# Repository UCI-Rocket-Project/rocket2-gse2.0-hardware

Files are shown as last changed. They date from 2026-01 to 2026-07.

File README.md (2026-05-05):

# rocket2 Ground Support Electronics (GSE) 
Current version: v2.1  
Documentation is rendered with MKDocs: [Click Here](https://uci-rocket-project.github.io/rocket2-gse2.0-hardware/)  

# CAD



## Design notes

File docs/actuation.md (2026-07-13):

# Overview
Last updated: 7/12/26

By: Robert Woo

The GSE supports 3 actuator types: Solenoid Valves, E-matches, and the Alarm.

The GSE includes:

- 12 Solenoid Valve output channel
- 2 E-match output channels
- 1 Alarm output channels

# Solenoid Valves

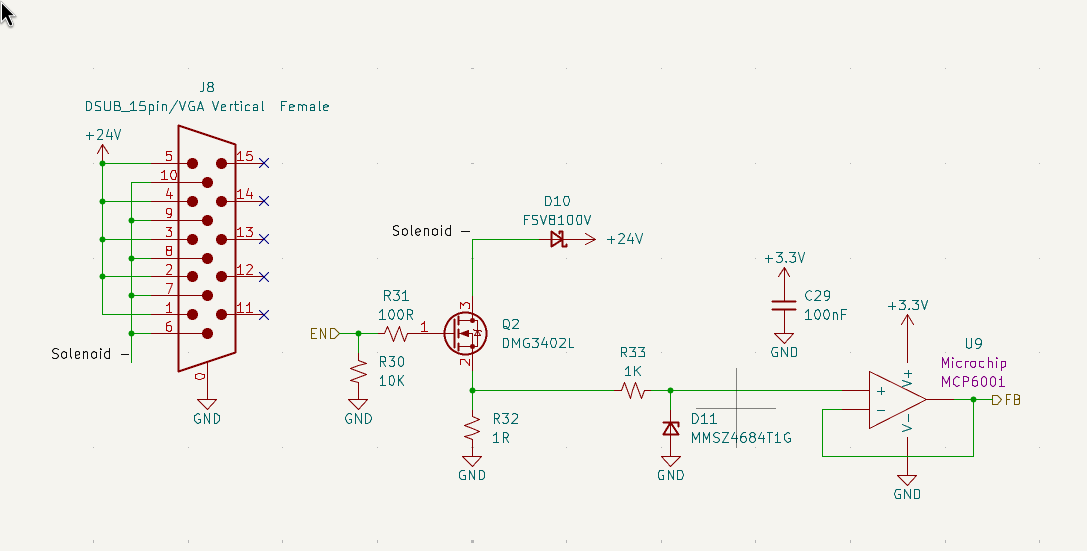
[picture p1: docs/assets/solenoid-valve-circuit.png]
Solenoid Valve Circuit


The GSE includes 12 solenoid valve out channels.

Solenoids are basically as inductors, which is why D10 is there. It's called a flyback diode, and its purpose is the allow the solenoids
to dissipate its stored magnetic field from an on-to-off state. D10's model has insanely high rating to deal with transients when current
on and off through an inductive element.

R31, R30, and Q2 are used to turn on and off the solenoid through the MCU's GPIO pin. R30 is for nominal off-state and R31 is to deal with overshoots in MOSFET gate voltages.

R32 should be a high wattage, 1 ohm resistor that is used primarily to read if there is current passing through the solenoid electrically.
Our solenoids draw about 500mA under 24V, so V=IR shows us that the voltage above R32 should be about 0.5V

The remaining components are double protection send this 0.5V back to an ADC pin on GSE's MCU. D11 is a zener diode which in combination 
with R33 will clamp unsafe voltage to the op-amp (U9) and pass thr current to ground. U9 just passed whatever voltage is at the + pin on 
op-amp, but acts as a buffer between the potential 24V that this circuit can see and potentially send to the MCU. You don't want to blow 
up the MCU by sending it 24V.

# E-matches

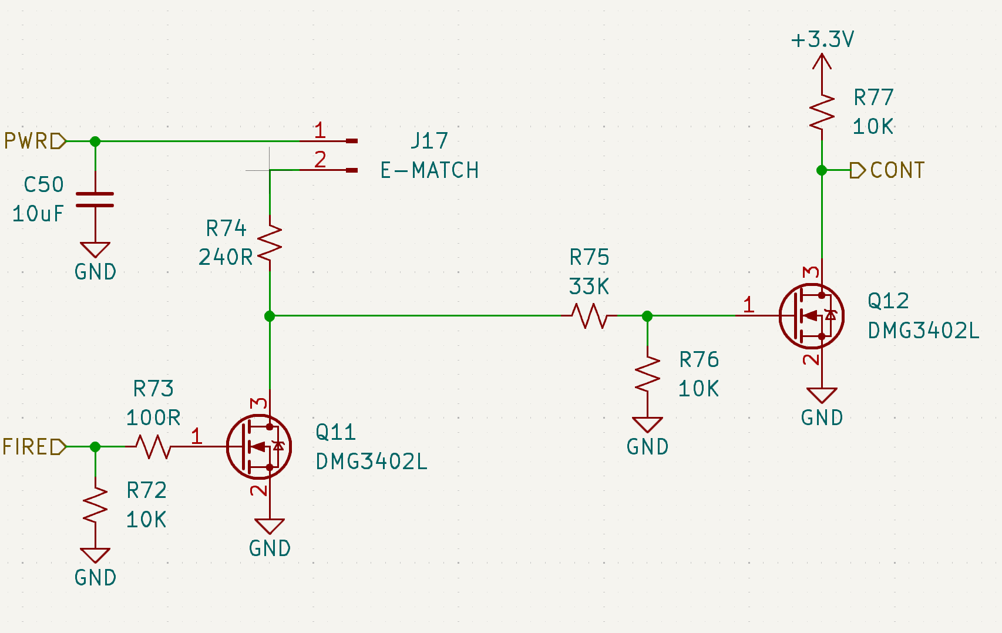
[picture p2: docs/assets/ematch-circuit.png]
E-match Circuit


The GSE includes 2 e-match output channels.

The e-match driver circuit uses a two-stage MOSFET switching configuration to safely control current delivery to the e-match load and read status of the circuit.

In the image, the node PWR will see either 0 or 24V depending on the if the arming is key is switched on or not to pass through the 
voltage

The CONT pin is a GPI that reads a logical high or low depending if there is voltage at the gate of the mosfet (Q12). If there is voltage
there, that means:

* the key is armed
* an ematch is connected between the screw terminals on GSE

R75 and R76 are used to step down the voltage to the gate of MOSFET to keep the voltages of the MOSFET in its operating range

R73, R72, and Q11 are used actually start an ematch. if FIRE goes to 3.3V from the MCU, the MOSFET will complete the circuit for the 
ematch to blow it.

**R74 is really important.** The MOSFET (DMG3402L) has a max current between drain and source (Id) of 4.0A. **R74 is there so that the MOSFET never fails from overcurrent. THe failure mode from overcurrent is the MOSFET always completing the circuit** 

# Alarm

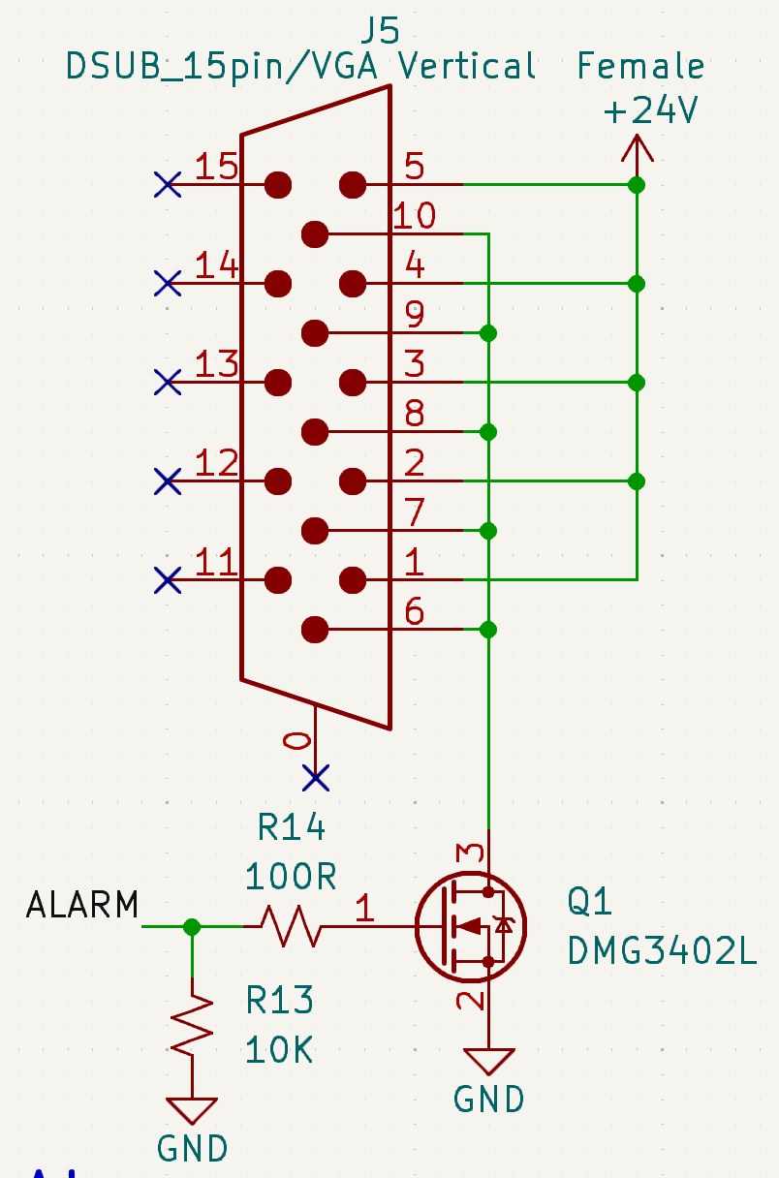
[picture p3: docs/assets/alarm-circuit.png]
Alarm Circuit


The GSE includes only 1 alarm output channel.

In the alarm driver circuit, a MCU GPIO control signal (ALARM) drives the gate of an N-channel MOSFET through a series resistor (R14). In parallel, a pull-down resistor (R13) tied to GND ensures a defined OFF state and prevents the build-up of residual charge.

Simple low-side mosfet switch

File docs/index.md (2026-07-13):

# GSE Docs
Last updated: 7/12/26

By: Robert Woo

## System Overview

For MOCH4, the GSE (Ground Support Electronics) is a 4-layer PCBA that controls the propulsion feedsystem on the ground. 

It is responsible for data collection from potentiometers, pressure transducers (PTs), and k-type thermocouplers (TC), and controls valve actuation through electric solenoids. 

Control is done entirely throught STM32F105RCT6 microntroller on the board and data collection collected either through the STM32 through the ethernet port on the back of the board or an NiDAQ (Currently a USB-6421) to collect this data from a PC.

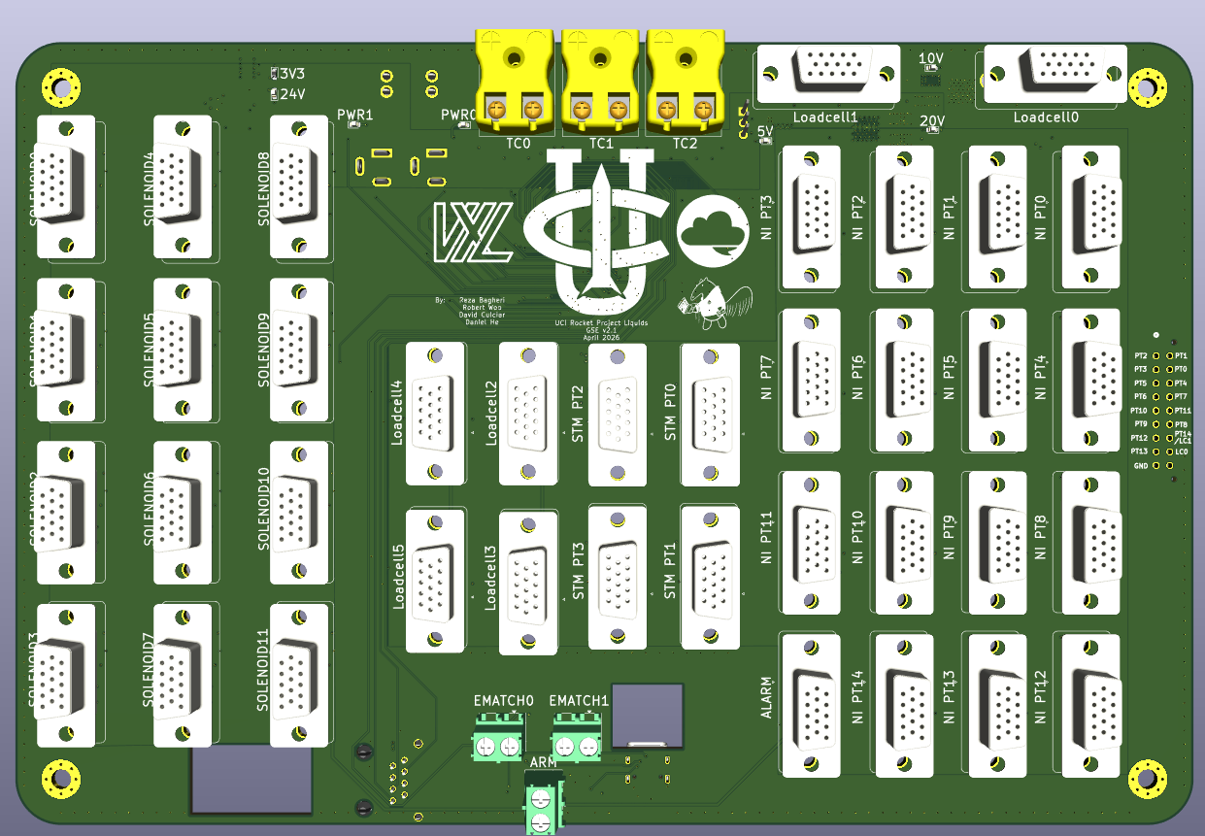
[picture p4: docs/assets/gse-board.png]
GSE PCB


## Inputs and Outputs
| Parameter | Value | Connector | Usage |
|---|---|---|---|
| Power ports | 24V DC, 2 redundant ports | 5.5mm barrel jack | Power board |
| Ethernet | 1 port | RJ45 uart-to-eth | Send/Recieve data 
| USB | 1 port | USB-C | Backup/debug data port, not in use|
| NiDAQ port | 1 port, 16 pins | 2x9 MOLEX | Output sensor voltages to NiDAQ |
| Solenoid ports | 24V 12 channels/ports | 15 pin, 3 row DSUB / VGA  | On/Off solenoid actuation |
| Ni PT ports | 20V 14/15 ports | 15 pin, 3 row DSUB / VGA  | Finds pressure readings to be read by the NIDAQ |
| STM32 PT ports | 20V 4 ports | 15 pin, 3 row DSUB / VGA  | Finds pressure readings to be read by an ADC, data transmitted over eth |
| Ni Loadcell ports | 10V 2 ports | 15 pin, 3 row DSUB / VGA  | Finds force readings from a 4 pin load to be read by the NiDAQ |
| STM32 Loadcell ports  | 10V 4 ports | 15 pin, 3 row DSUB / VGA  | Finds force readings from a 4 pin load cell to be read by an ADC data transmitted over eth |
| TC ports | 3 ports | 2 pin k-type TC plug | Reads temperature from a k-type TC, data sent over eth | 
| Ematch circuit | 2 ports, 1 arming port | Screw terminals | Sets off an e-match to start engine combustion |

## Circuits
- [Power](power.md)
- [Sensing](sensing.md) 
- [Compute](compute.md) TBD later
- [Communications](communications.md) TBD later
- [Actuation](actuation.md)

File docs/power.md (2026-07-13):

# Power
Last updated: 7/12/26

By: Robert Woo

The GSE takes in a 24V supply via 2 redundant, 5.5mm barrel jack connectors. Only 1 ports is needed to turn power the board. 1 buck regulator and 3 Linear Drop-outs 
(LDOs) are used to step down this input voltage to various voltages for sub-circuits on GSE v2.1

---

## Power Input

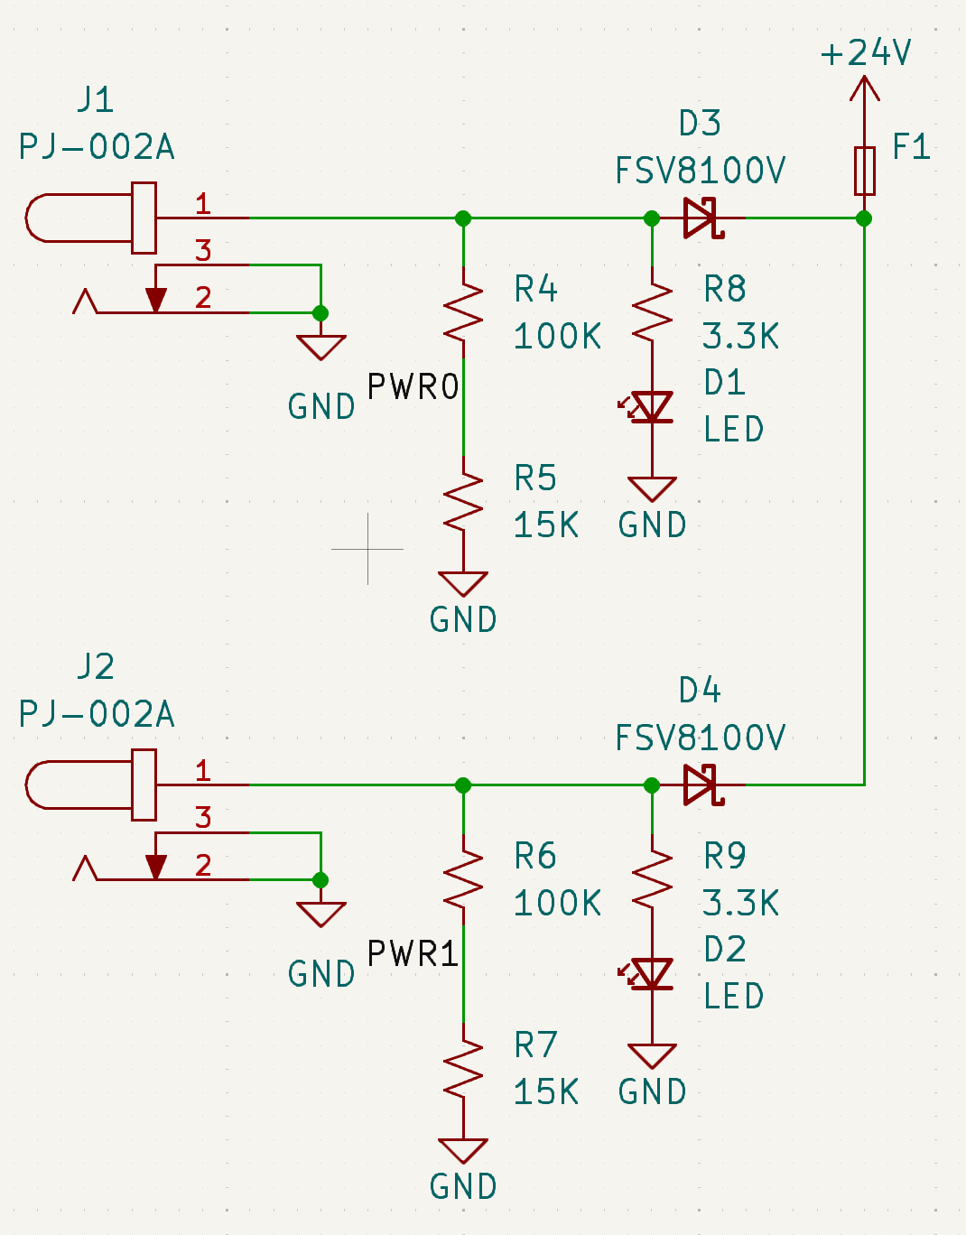
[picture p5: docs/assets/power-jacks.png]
Power Jacks


24V DC Power is accepted via two barrel jacks intended for redundant use, with only one input used at a time. Supplies the 24V power rail.

Each input is monitored by a voltage divider (R4 & R5, and R6 & R7), which feeds into the PWR0 and PWR1 GPIO pins for power detection and input voltage readings.

Schottky diodes (100V, 8A) are used to prevent current backflow between the 2, redundant, power supply inputs. 

LED indicators (D1 & D2) provide visual confirmation when input voltage is present at each jack.

Here's an example of what kind of power brick is used to power the board : 
[Power brick](https://www.amazon.com/dp/B0D5B33JCH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)

---

## Power regulators

GSE v2.1 currently has 3 LDOs and 1 buck regulator to power the following voltage rails:

| Component | Input Voltage | Output Voltage | Output Current |
|---|---|---|---|
| [Buck regulator (U5)](https://jlcpcb.com/partdetail/Monolithic_PowerSystems-MP2338GTLZ/C7210174) | 24V nominal | 3.3V | 3A |
| [LDO regulator (U2)](https://jlcpcb.com/partdetail/DiodesIncorporated-AS78L05RTRE1/C90471) | 24V nominal | 5V | 100 mA |
| [LDO regulator (U6)](https://jlcpcb.com/partdetail/TexasInstruments-UA78M10CKVURG3/C2868719) | 24V nominal | 10V | 500 mA |
| [LDO regulator (U7)](https://jlcpcb.com/partdetail/ROHMSemicon-BA78M20FPE2/C5336616s) | 24V nominal | 20V | 500 mA |

## Synchronous Buck Regulator: 3.3V Logic Level

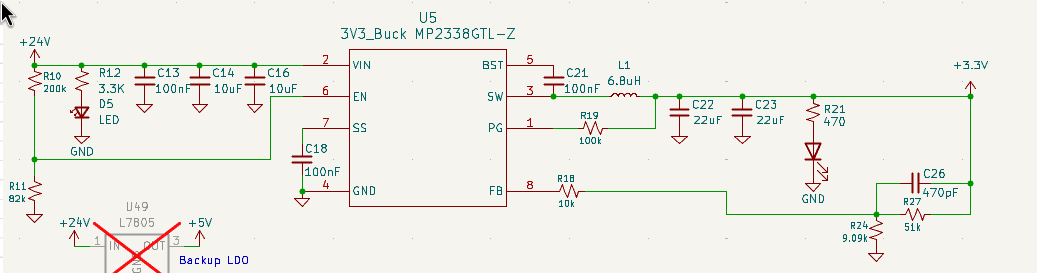
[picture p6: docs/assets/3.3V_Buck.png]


A synchronous buck regulator converts the 24V power rail into the 3.3V logic level supply rail. This circuit basically follows the datasheet exactly for a 3.3V 
output, and this buck converter was chosen mainly because it internally compensates the feedback loop. Aka, buck converters are hard and this synchronous buck 
converter, the higher efficency version, was easy AF in drop in.

---

### TROUBLESHOOTING / BUCK FAILURE

During usage of GSE v2.1 in Spring 2026, this buck converter failed/exploded after plugging in a 24V power supply into the barrel jacks of the board. This caused
everything on 3.3V bus to fry. DEAD AF BOARD

This was caused by inductive kick. Basically, wires has parasitive inductance in them. Inductors resists a change in current, and when you say, plug in a power
supply into a PCB, the inductance of the wires will causing an overshoot in voltage because current is basically infinite the moment charges start moving.

This was troubleshooted and found out mainly because GSE v2.1 was tested previously wiwth a DC power supply and shorter cables comparative to the 24 power brick
later used.

Inductive Kick
The picture above is just unplugging and replugging in the 24V power brick and reading the voltage that the buck converter would see with an oscilloscope with a single
shot trigger setting. As you can see, the buck converter sometime can see a max of 68V whenever you plug power in :0000000.

---

The solution: Put an electrolytic capacitor in parallel with Vin of the buck converter. Electrolytic capacitors generally have a high Equivalent Series Resistance (ESR)
can and was used on GSE v2.1 to slow down the infinite current that this buck converter would see.

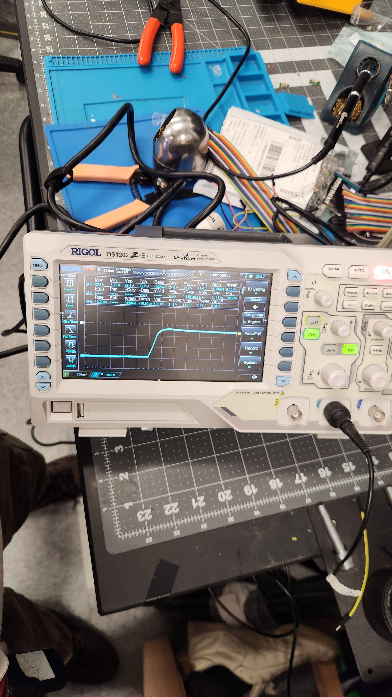
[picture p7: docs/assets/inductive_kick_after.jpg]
Inductive Kick

This was result with the oscilloscope probing the same point as before, but with an electrolytic capacitor in parallel with the other ceramic capacitors for the MP2338GTL-Z
Much better at dampening out the overshoot

---
#### Recommendation in the future:
&nbsp;

1. CHANGE THE BUCK CONVERTER IC

The MP2338GTL-Z has a highest input voltage rating 30V, which is low and why buck converter failed and killed everything from it downstream. NASA's derating guidelines say
to use components that can tolerate about 1.6 times the expected voltage range in normal operation. So get a buck converter that can take 38.4V or higher.

2. Still add the electrolytic capacitor in parallel with the next buck converter, just in case.

## Low Dropout (LDO) Regulators: 20V, 10V, 5V

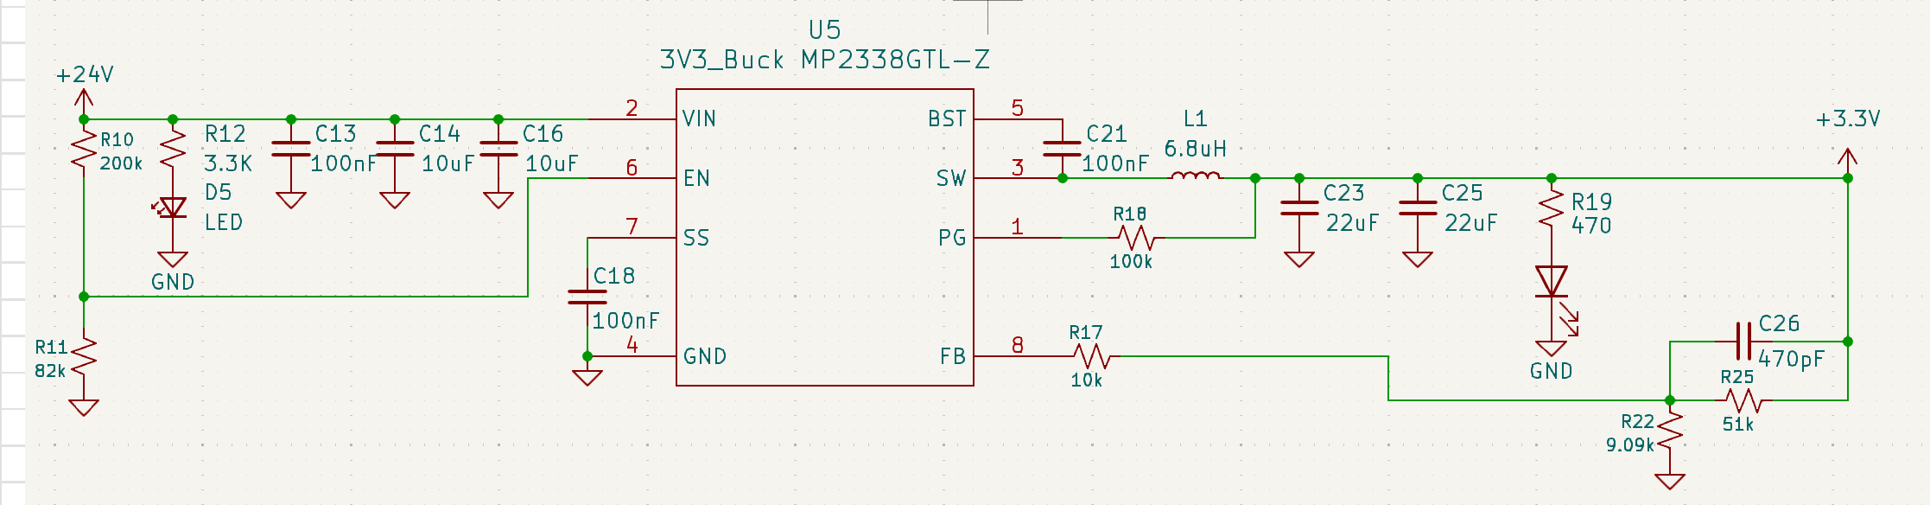
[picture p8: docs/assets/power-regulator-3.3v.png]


Three independent LDO regulators convert the 24V power rail into 5V, 10V, and 20V supply rails, providing isolated power domains for downstream subsystems. 

The 20V and 10V LDOs are used to power PTs/Potentiometers and Loadcells respectively. This was done because LDOs, while less efficient, have Power Supply Rejection Ratio 
(PSRR). This ratio is a curve that represents how well the IC can filter out noise at the input of the regulator, which allows for the output voltage powering the sensors
to be clean. It is not uncommon to see 60Hz oscillations in sensor readings because that is the frequency that the wall power is oscillating at.

Input decoupling capacitors (C12, C19, C22) stabilize each LDO supply rail and minimize input ripple. Output capacitors (C15, C20, C24) are required to ensure stable operation of
the regulators' internal control loops.

LED indicators (D56, D55, D54) provide visual confirmation of the LDOs functionality.

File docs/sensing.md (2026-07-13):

# Overview
Last updated: 7/12/26

By: Robert Woo
The GSE supports 4 sensor types: Pressure Transducers (PTs), Potentiometers (POTs), Load Cells, and Thermocouples (TCs).

The GSE includes:

* 18-19 PT/POTS input channels
    * 14-15 high speed NiDAQ channels
    * 4 External I2C ADC channels
* 5-6 load cell input channels
    * 1-2 high speed NiDAQ channels
    * 4 External I2C ADC channels 
* 3 TC input channels

The reason for the 14 - 15 Ni PT channels an 1-2 Ni Load cell channels is because the board can toggle the connection between the ports:

* Loadcell1
* NI PT14

being connected to pin 16 on the molex connector that connects to the NiDAQ

---

## Hardware Specifications

| Sensor Type | Input Voltage |
|---|---|
| [Pressure Transducers](https://transducersdirect.com/wp-content/uploads/2018/07/TDH40-8.19.pdf) | 20V 
| [Voltage Sensors](https://www.digikey.com/en/products/detail/tt-electronics-bi/P160KNPD-4FC20B10K/2408891) | 20V |
| [Load Cells](https://www.interfaceforce.com/wp-content/uploads/SSM_SSM2-1.pdf) | 10V |
| [Thermocouples](link) | 3.3V |

---

## Pressure Transducers (PTs) & Potentiometers (POTs)

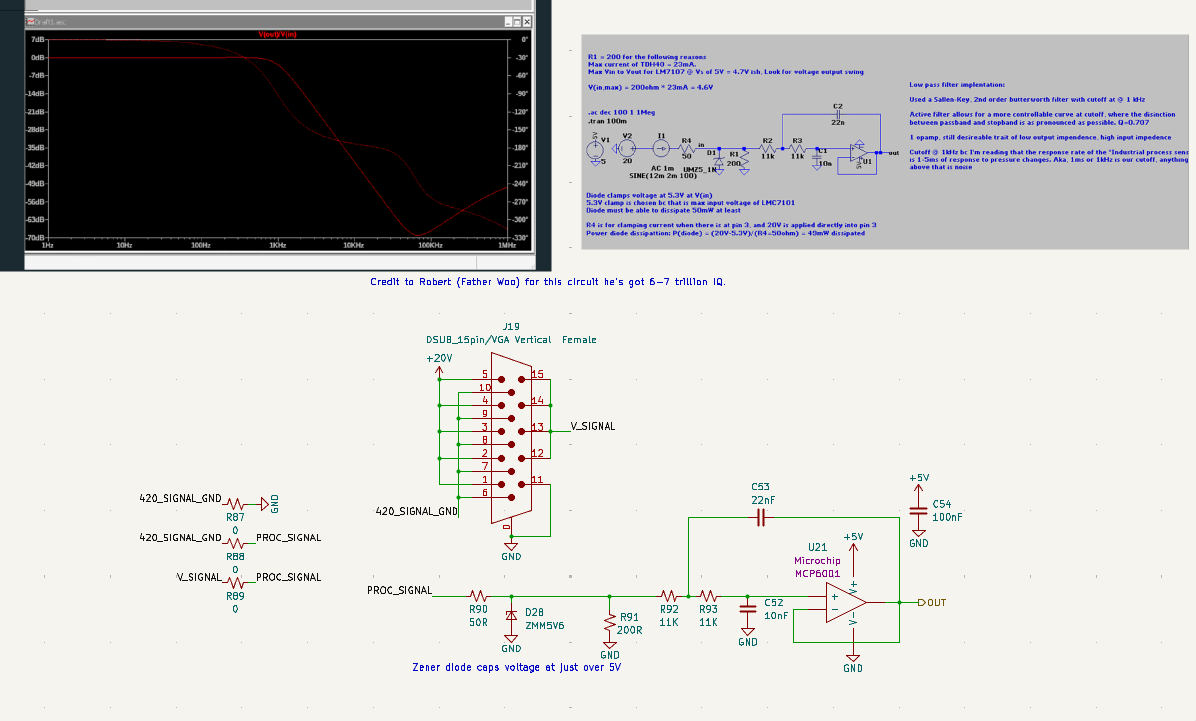
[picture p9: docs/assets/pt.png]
PT Circuit


The GSE includes 18-19 pressure transducer (PT/POTs) input channels.

PTs and POTs share the same circuit since the signal conditioning is the same. The unviersal adapter board steps down the voltage that
the POT would see in order have the POT output a range of 0-5V.

On GSE v2.1, this circuit can be configured for either 3 wire, voltage-sensing pressure transducers or 2 wire, 4-20mA pressure transducers

* For voltage-sensing PTs, populate R87 and R88 and depopulate R89
* For 4-20mA PTs, do the opposite of the voltage-sensing PTs

Each PT/POT 0-5V signal is received through a DSUB connector and routed through a low-pass filter that removes high-frequency noise 
before digitization.

This filter is implemented as a 2nd-order active Sallen-Key topology with a Butterworth response (flat passband and slow roll-off) and a 
cutoff frequency of 1kHz (fastest possible a PT can response to pressure change).

A Zener diode (D25) at the input provides overvoltage protection, with breakdown at ~5.5V to protect downstream circuitry. 

The conditioned signals are then fed either to the:

* The Molex port, which connects to the NI DAQ for high speed PT/POTS readings.
* An external I2C ADC, for slower PT/POTS

[Reference](https://www.ti.com/lit/an/sboa226/sboa226.pdf?ts=1783865113347)

### Future changes
The circuit is fine, but GSE v2.1 done goofed and forget the pullups for I2C. Dumbass robert

--- 

## Load Cells 

The GSE includes 5-6 load cell input channels.

Each differential load cell signal is received through a DSUB connector and routed through a low-pass filter followed by an op-amp differential-to-single-ended converter.

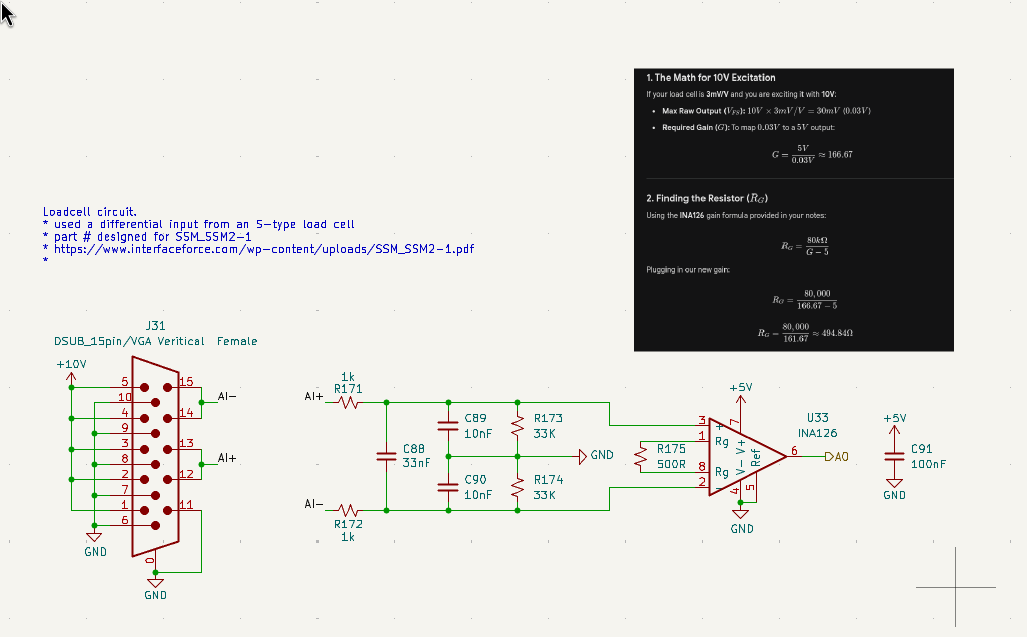
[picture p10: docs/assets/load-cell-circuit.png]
Load Cell Circuit


This filter is implemented as a passive RC network with both differential and common-mode low-pass filtering. The cutoff frequency is ~2.
1kHz, selected to reduce high-frequency noise prior to amplification.

Then the differential amplifier converts the filtered load cell differential signal to a single-ended voltage suitable for digitization.

Loadcells output a mV voltage difference between the AI+ and AI- pins. The differential amplifier takes in, say for example, a voltage 
difference between AI+ and AI- of 10mV, and amplifies that signal into a present voltage range, depending on gain, which is chosen by the
value of resistor between the RG pins. Read the datasheet for the formulas

The conditioned signals are then fed to the NI DAQ or the I2C ADC for analog-to-digital conversion.

--- 

### Future changes
Robert done goofed on this circuit as well. 2 problems with the differential amplifier:

1. The REF pin is tied to ground and the IC isn't rail-to-rail
    * From the datasheet, the INA126U2K5 being not rail-to-rail means that positive and negative "output voltage swing" is -0.75V the
    positive rail, and + 0.8V the negative rail. This is a problem when reading mV readings. From the formulas in the datasheet, if your 
    expected output range is between the negative rail and +0.8V of the negative rail, the ouput will now change
    * Fix: add a voltage rail with a voltage somewhere above 0.8V and keep the negative rail of the differential amplifier at 0V
        * This will allow for the diff amplifier to have the output voltage stay in its operating range so its output voltage will change to the loadcells mV differenital changes

2. The positive rail is powered by 5V
    * This was dumb by robert. The loadcell in the loadcell circuit is powered by 10V. Loadcells use a wheatstone bridge circuit to 
    output mV differences in its differential signal to represent force. Wheastone bridges are basically voltage dividers, the V+ and V- 
    signals, aka **the common-mode voltage of AI+ and AI- of the loadcell is 5V**. The differential amplifier can't operate if the 
    voltages at its IN+ and IN- pins are higher than the voltage on the V+ rail.    
    * Fix: Power V+ with 10V as well in the next iteration, change the gain value with (Rg) to stay within a 0-5V range and add some
    voltage clamping circuit so that you don't blow up the external i2c adc.
        * You should keep the 10V on the loadcell power to move as far away from the noise floor as possible
        * Add something like a voltage follower on the output of the diff amplifier if for whatever reason (AI+ - Ai-) is extremely high 
        and you don't want to send 10V to the external i2c adc. That ADC can handle a max of 5.0V + 0.3V

# Thermocouples (TCs)

The GSE includes 3 thermocouple (TC) input channels.

Each TC signal is received through a AM-K-PCB connector (specialized connector for K-type thermocouples) and routed through a low-pass filter that removes high frequency noise before digitization.

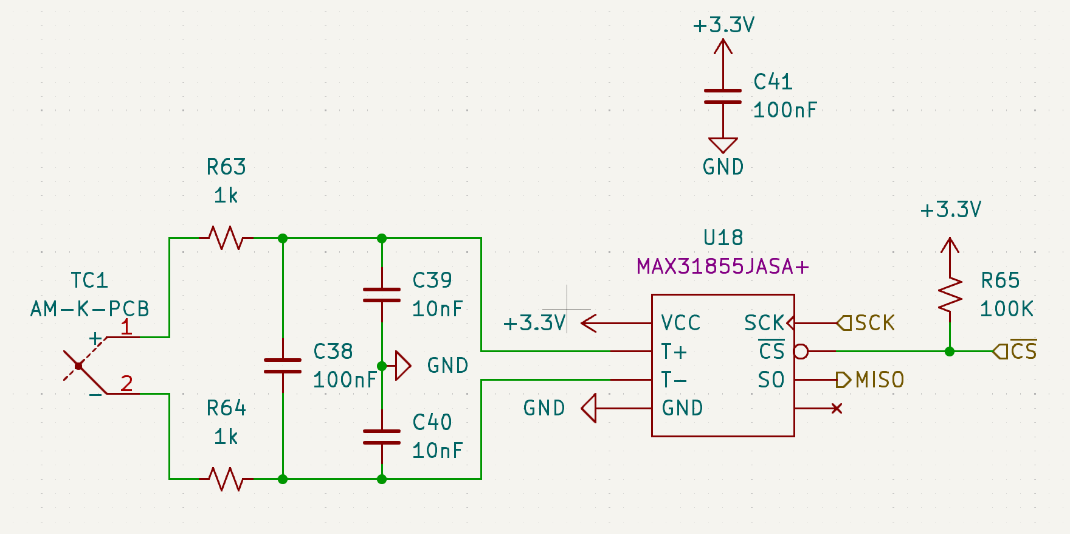
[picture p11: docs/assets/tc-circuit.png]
Thermocouple Circuit


This filter is implemented as a passive RC network with both differential and common-mode low-pass filtering. 

The conditioned signals are then fed to dedicated ADCs (U18, U19, U20 respectively for each channel), from which they are read by the STM32 microcontroller.

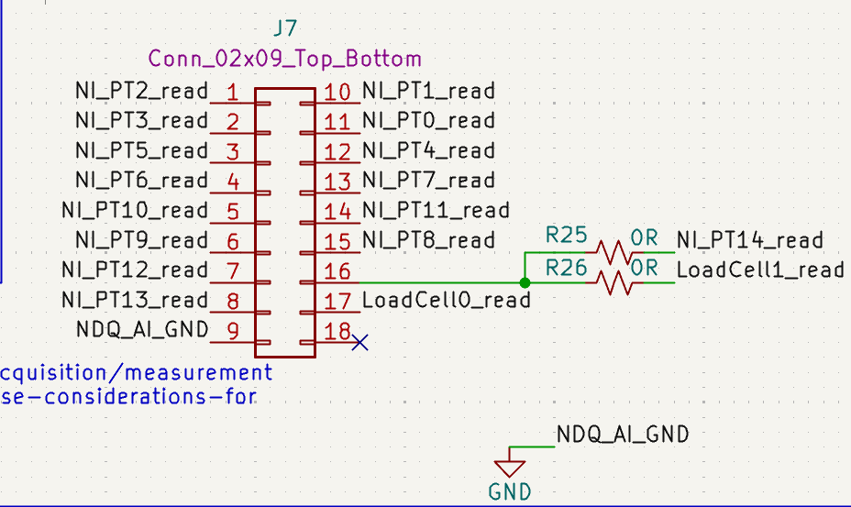
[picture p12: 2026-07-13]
docs/assets/molex.png

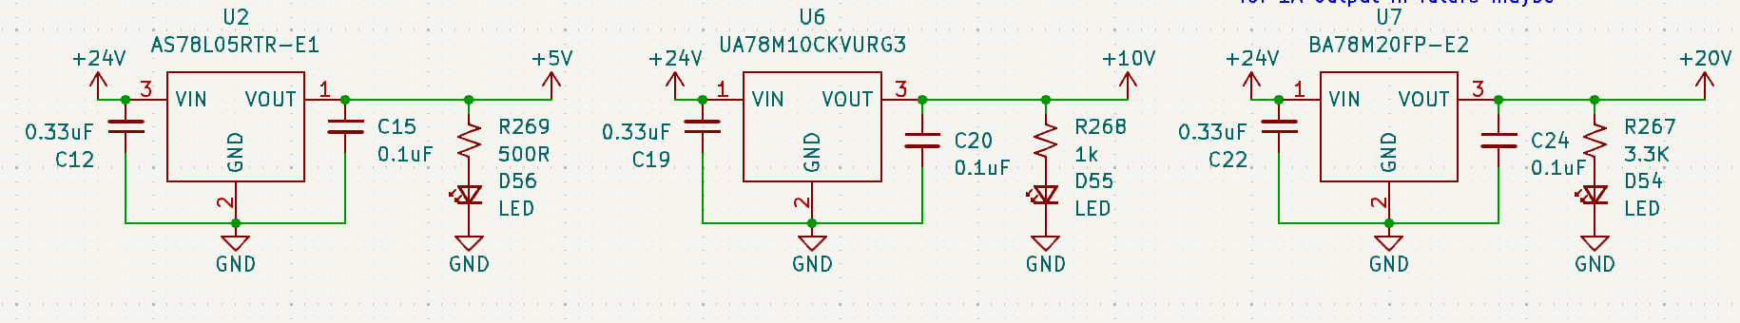
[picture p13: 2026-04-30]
docs/assets/LDOs.png

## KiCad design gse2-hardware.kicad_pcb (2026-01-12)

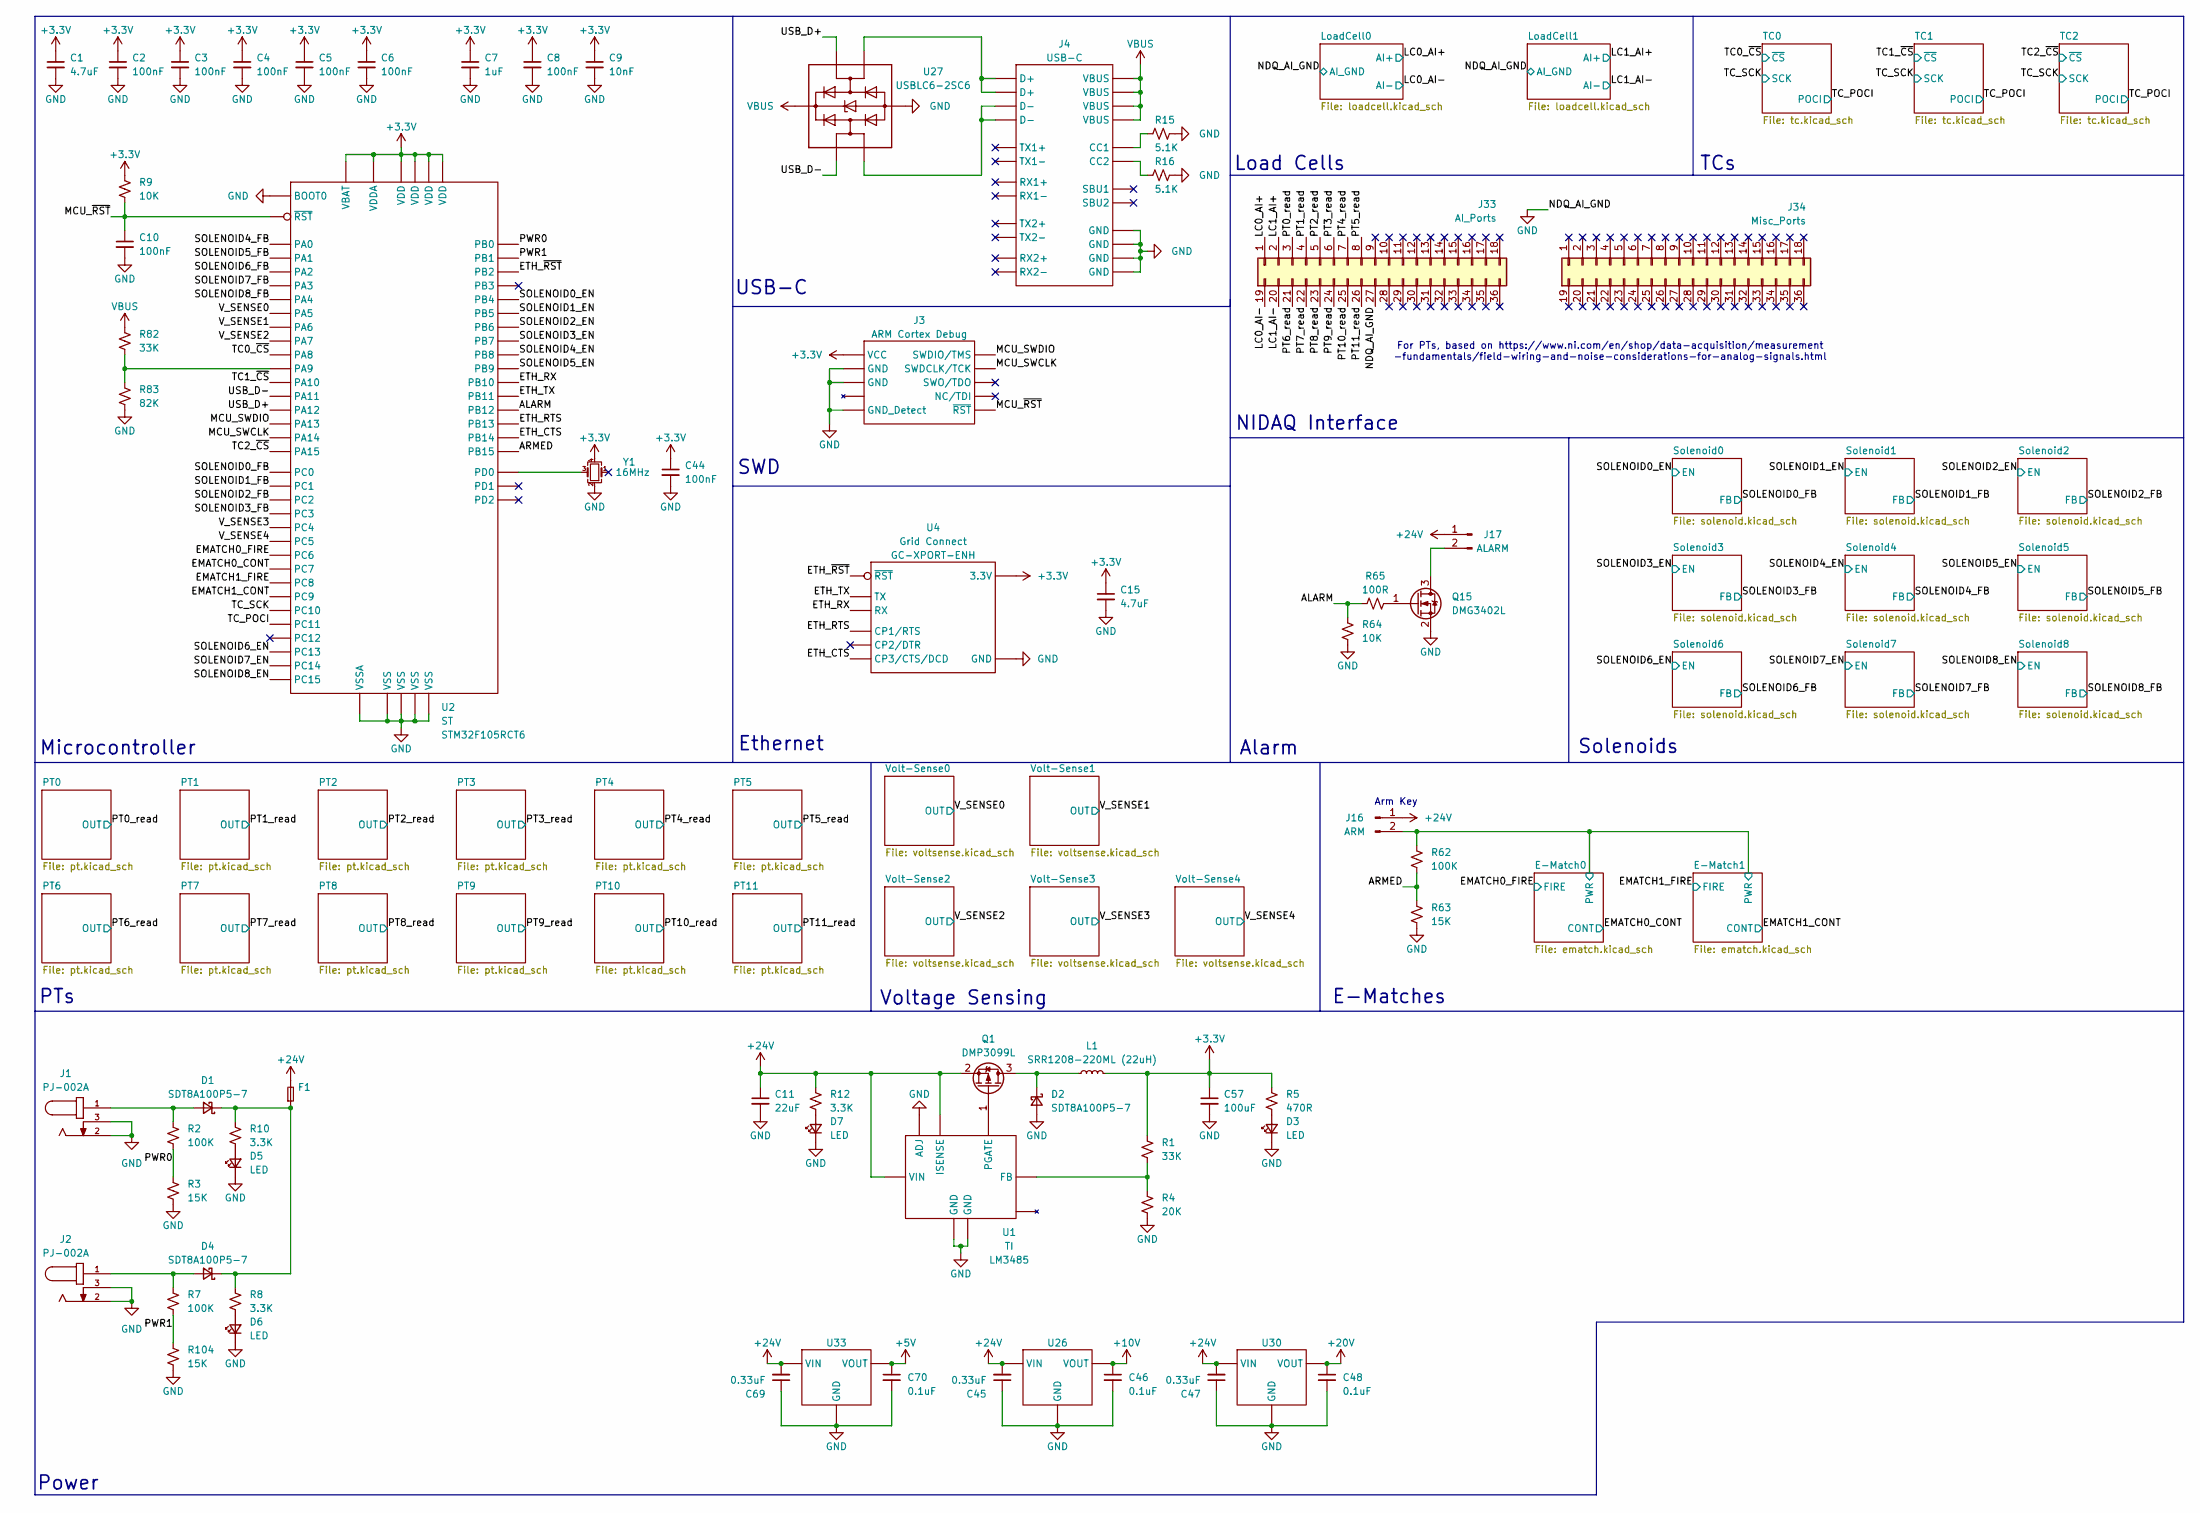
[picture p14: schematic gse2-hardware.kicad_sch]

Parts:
C1, C15: 4.7uF; C_0603_1608Metric; Part # Generic 4.7uF 6.3V X7R 0603 MLCC
C2, C3, C4, C5, C6, C8, C10, C44: 100nF; C_0603_1608Metric; Part # Generic 100nF 6.3V X7R 0402 MLCC
C7: 1uF; C_0603_1608Metric; Part # Generic 1uF 6.3V X7R 0402 MLCC
C9: 10nF; C_0603_1608Metric; Part # Generic 10nF 6.3V X7R 0402 MLCC
C11: 22uF; C_0603_1608Metric; Part # Generic 22uF 35V X5R 1206 MLCC
C45, C47, C69: 0.33uF; C_0603_1608Metric; Part # Generic 22uF 35V X5R 1206 MLCC
C46, C48, C70: 0.1uF; C_0603_1608Metric; Part # Generic 22uF 35V X5R 1206 MLCC
C57: 100uF; C_0603_1608Metric; Part # Generic 100uF 6.3V X5R 1206 MLCC
D1, D2, D4: SDT8A100P5-7; D_PowerDI-5; Part # SDT8A100P5-7
D3, D5, D6, D7: LED; LED_0603_1608Metric; Part # Generic Red 0603 LED
F1: Fuseholder_Blade_Mini_Keystone_3568; Part # 3568
J1, J2: PJ-002A; CUI_PJ-002A
J3: ARM Cortex Debug; PinHeader_2x05_P1.27mm_Vertical_SMD; Part # Generic 2x5 1.27mm SMD Pin Header
J4: USB-C; USB_C_Receptacle_GCT_USB4105-xx-A_16P_TopMnt_Horizontal; Part # USB4105-GF-A
J16: ARM; TerminalBlock_MetzConnect_Type055_RT01502HDWU_1x02_P5.00mm_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
J17: ALARM; TerminalBlock_MetzConnect_Type055_RT01502HDWU_1x02_P5.00mm_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
J33: AI_Ports
J34: Misc_Ports
L1: SRR1208-220ML (22uH); L_Bourns_SRR1208_12.7x12.7mm; Part # SRR1208-220ML
Q1: DMP3099L; SOT-23-3; Part # DMP3099L
Q15: DMG3402L; SOT-23-3; Part # DMG3402L
R1, R82: 33K; R_0603_1608Metric; Part # Generic 33K 1% 0402 Resistor
R2, R7, R62: 100K; R_0603_1608Metric; Part # Generic 100K 1% 0402 Resistor
R3, R63, R104: 15K; R_0603_1608Metric; Part # Generic 15K 1% 0402 Resistor
R4: 20K; R_0603_1608Metric; Part # Generic 20K 1% 0402 Resistor
R5: 470R; R_0603_1608Metric; Part # Generic 470R 1% 0402 Resistor
R8, R10, R12: 3.3K; R_0603_1608Metric; Part # Generic 3.3K 1% 0402 Resistor
R9, R64: 10K; R_0603_1608Metric; Part # Generic 10K 1% 0402 Resistor
R15, R16: 5.1K; R_0603_1608Metric; Part # Generic 5.1K 1% 0402 Resistor
R65: 100R; R_0603_1608Metric; Part # Generic 100R 1% 0402 Resistor
R83: 82K; R_0603_1608Metric; Part # Generic 82K 1% 0402 Resistor
U1: VSSOP-8_3x3mm_P0.65mm; Part # LM3485
U2: LQFP-64_10x10mm_P0.5mm; Part # STM32F105RCT6
U4: GC-XPORT; Part # GC-XPORT-ENH
U26: TO-252-2
U27: USBLC6-2SC6; SOT-23-6
U30: TO-252-2; Part # BA78M20FP-E2
U33: SOT-89-3
Y1: 16MHz; Crystal_SMD_2016-4Pin_2.0x1.6mm; Part # ECS-1633-160-BN-TR

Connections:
+3.3V: C1.1, C2.1, C3.1, C4.1, C5.1, C6.1, C7.1, C8.1, C9.1, C15.1, C44.1, C57.1, J3.1 (VCC), L1.2, R1.2, R5.2, R9.2, U2.1 (VBAT), U2.13 (VDDA), U2.19 (VDD), U2.32 (VDD), U2.48 (VDD), U2.64 (VDD), U4.2 (3.3V), Y1.4; also elsewhere on the board
+5V: C70.1, U33.3 (VOUT); also elsewhere on the board
+10V: C46.1, U26.3 (VOUT); also elsewhere on the board
+20V: C48.1, U30.3 (VOUT); also elsewhere on the board
+24V: C11.1, C45.2, C47.2, C69.2, F1.2, J16.1, J17.1, Q1.2 (S), R12.2, U1.1 (ISENSE), U1.8 (VIN), U26.1 (VIN), U30.1 (VIN), U33.1 (VIN); also elsewhere on the board
/ALARM: R64.2, R65.1, U2.33 (PB12)
/ARMED: R62.1, R63.2, U2.36 (PB15)
/E-Match0/PWR: J16.2, R62.2; also elsewhere on the board
/EMATCH0_CONT: U2.38 (PC7); also elsewhere on the board
/EMATCH0_FIRE: U2.37 (PC6); also elsewhere on the board
/EMATCH1_CONT: U2.40 (PC9); also elsewhere on the board
/EMATCH1_FIRE: U2.39 (PC8); also elsewhere on the board
/ETH_CTS: U2.35 (PB14), U4.8 (CP3/CTS/DCD)
/ETH_RTS: U2.34 (PB13), U4.6 (CP1/RTS)
/ETH_RX: U2.29 (PB10), U4.5 (RX)
/ETH_TX: U2.30 (PB11), U4.4 (TX)
/ETH_~RST: U2.28 (PB2), U4.3 (~RST)
/MCU_SWCLK: J3.4 (SWDCLK/TCK), U2.49 (PA14)
/MCU_SWDIO: J3.2 (SWDIO/TMS), U2.46 (PA13)
/MCU_~RST: C10.1, J3.10 (~RST), R9.1, U2.7 (~RST)
/PWR0: R2.1, R3.2, U2.26 (PB0)
/PWR1: R7.1, R104.2, U2.27 (PB1)
/SOLENOID0_EN: U2.56 (PB4); also elsewhere on the board
/SOLENOID0_FB: U2.8 (PC0); also elsewhere on the board
/SOLENOID1_EN: U2.57 (PB5); also elsewhere on the board
/SOLENOID1_FB: U2.9 (PC1); also elsewhere on the board
/SOLENOID2_EN: U2.58 (PB6); also elsewhere on the board
/SOLENOID2_FB: U2.10 (PC2); also elsewhere on the board
/SOLENOID3_EN: U2.59 (PB7); also elsewhere on the board
/SOLENOID3_FB: U2.11 (PC3); also elsewhere on the board
/SOLENOID4_EN: U2.61 (PB8); also elsewhere on the board
/SOLENOID4_FB: U2.14 (PA0); also elsewhere on the board
/SOLENOID5_EN: U2.62 (PB9); also elsewhere on the board
/SOLENOID5_FB: U2.15 (PA1); also elsewhere on the board
/SOLENOID6_EN: U2.2 (PC13); also elsewhere on the board
/SOLENOID6_FB: U2.16 (PA2); also elsewhere on the board
/SOLENOID7_EN: U2.3 (PC14); also elsewhere on the board
/SOLENOID7_FB: U2.17 (PA3); also elsewhere on the board
/SOLENOID8_EN: U2.4 (PC15); also elsewhere on the board
/SOLENOID8_FB: U2.20 (PA4); also elsewhere on the board
/TC0_~CS: U2.50 (PA15); also elsewhere on the board
/TC1_~CS: U2.43 (PA10); also elsewhere on the board
/TC2_~CS: U2.41 (PA8); also elsewhere on the board
/TC_POCI: U2.52 (PC11); also elsewhere on the board
/TC_SCK: U2.51 (PC10); also elsewhere on the board
/USB_D+: U2.45 (PA12), U27.4 (I/O2)
/USB_D-: U2.44 (PA11), U27.6 (I/O1)
/V_SENSE0: U2.21 (PA5); also elsewhere on the board
/V_SENSE1: U2.22 (PA6); also elsewhere on the board
/V_SENSE2: U2.23 (PA7); also elsewhere on the board
/V_SENSE3: U2.24 (PC4); also elsewhere on the board
/V_SENSE4: U2.25 (PC5); also elsewhere on the board
GND: C1.2, C2.2, C3.2, C4.2, C5.2, C6.2, C7.2, C8.2, C9.2, C10.2, C11.2, C15.2, C44.2, C45.1, C46.2, C47.1, C48.2, C57.2, C69.1, C70.2, D2.2 (A), D3.1 (K), D5.1 (K), D6.1 (K), D7.1 (K), J1.2, J1.3, J2.2, J2.3, J3.3 (GND), J3.5 (GND), J3.9 (GND_Detect), J4.A1 (GND), J4.A12 (GND), J4.B1 (GND), J4.B12 (GND), J33.27, Q15.2 (S), R3.1, R4.1, R15.1, R16.1, R63.1, R64.1, R83.1, R104.1, U1.2 (GND), U1.5 (ADJ), U1.6 (GND), U2.12 (VSSA), U2.18 (VSS), U2.31 (VSS), U2.47 (VSS), U2.60 (BOOT0), U2.63 (VSS), U4.1 (GND), U26.2 (GND), U27.2 (GND), U30.2 (GND), U33.2 (GND), Y1.2; also elsewhere on the board
unnamed: D1.2 (A), J1.1, R2.2
unnamed: D1.1 (K), D4.1 (K), F1.1, R8.2, R10.2
unnamed: D2.1 (K), L1.1, Q1.3 (D)
unnamed: D3.2 (A), R5.1
unnamed: D4.2 (A), J2.1, R7.2
unnamed: D5.2 (A), R10.1
unnamed: D6.2 (A), R8.1
unnamed: D7.2 (A), R12.1
unnamed: J4.A5 (CC1), R15.2
unnamed: J4.B5 (CC2), R16.2
unnamed: J4.A6 (D+), J4.B6 (D+), U27.3 (I/O2)
unnamed: J4.A7 (D-), J4.B7 (D-), U27.1 (I/O1)
unnamed: J17.2, Q15.3 (D)
unnamed: Q1.1 (G), U1.7 (PGATE)
unnamed: Q15.1 (G), R65.2
unnamed: R1.1, R4.2, U1.4 (FB)
unnamed: R82.1, R83.2, U2.42 (PA9)
unnamed: U2.5 (PD0), Y1.3
VBUS: J4.A4 (VBUS), J4.A9 (VBUS), J4.B4 (VBUS), J4.B9 (VBUS), R82.2, U27.5 (VBUS)

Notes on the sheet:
TCs
Microcontroller
E-Matches
SWD
Ethernet
PTs
Load Cells
Arm Key
Solenoids
Power
Voltage Sensing
For PTs, based on https://www.ni.com/en/shop/data-acquisition/measurement -fundamentals/field-wiring-and-noise-considerations-for-analog-signals.html
Alarm
USB-C
NIDAQ Interface

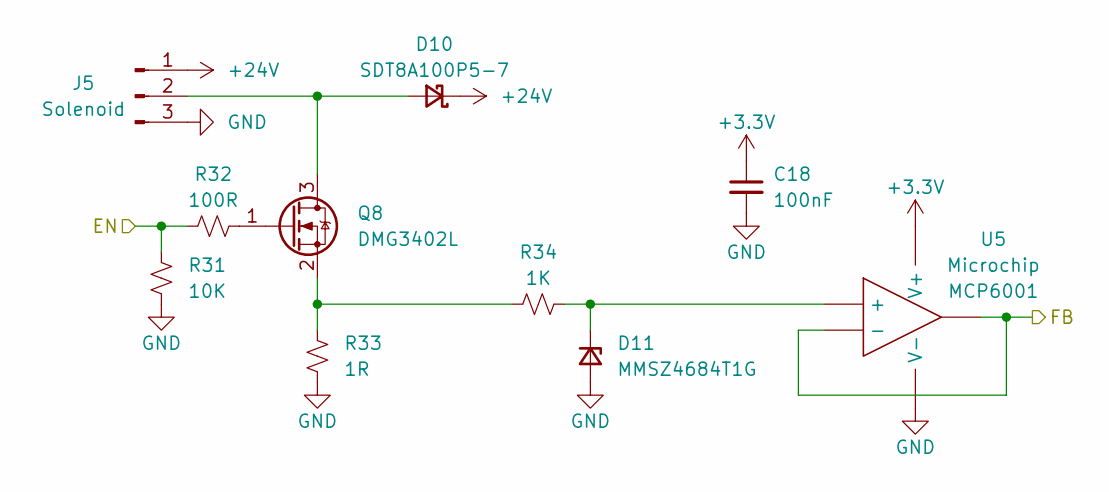
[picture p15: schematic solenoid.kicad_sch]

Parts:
C18: 100nF; C_0603_1608Metric; Part # Generic 100nF 6.3V X7R 0402 MLCC
D10: SDT8A100P5-7; D_PowerDI-5; Part # SDT8A100P5-7
D11: MMSZ4684T1G; D_SOD-123; Part # MMSZ4684T1G
J5: Solenoid; GX-16 3 pin
Q8: DMG3402L; SOT-23-3; Part # DMG3402L
R31: 10K; R_0603_1608Metric; Part # Generic 10K 1% 0402 Resistor
R32: 100R; R_0603_1608Metric; Part # Generic 100R 1% 0402 Resistor
R33: 1R; R_0603_1608Metric; Part # Generic 1R 2W 1% 2512 Resistor
R34: 1K; R_0603_1608Metric; Part # Generic 1K 1% 0402 Resistor
U5: SOT-23-5; Part # MCP6001

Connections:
+3.3V: C18.1, U5.5 (V+); also elsewhere on the board
+24V: D10.1 (K), J5.1; also elsewhere on the board
/SOLENOID0_EN: R31.2, R32.1; also elsewhere on the board
/SOLENOID0_FB: U5.1, U5.4 (-); also elsewhere on the board
GND: C18.2, D11.2 (A), J5.3, R31.1, R33.1, U5.2 (V-); also elsewhere on the board
unnamed: D10.2 (A), J5.2, Q8.3 (D)
unnamed: D11.1 (K), R34.2, U5.3 (+)
unnamed: Q8.1 (G), R32.2
unnamed: Q8.2 (S), R33.2, R34.1

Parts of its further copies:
C12, C13, C14, C16, C17, C19, C20, C21: 100nF; C_0603_1608Metric; Part # Generic 100nF 6.3V X7R 0402 MLCC
D8, D12, D14, D16, D18, D20, D22, D24: SDT8A100P5-7; D_PowerDI-5; Part # SDT8A100P5-7
D9, D13, D15, D17, D19, D21, D23, D25: MMSZ4684T1G; D_SOD-123; Part # MMSZ4684T1G
J6, J7, J8, J10, J11, J12, J13, J39: Solenoid; GX-16 3 pin
Q2, Q3, Q4, Q5, Q6, Q7, Q9, Q10: DMG3402L; SOT-23-3; Part # DMG3402L
R11, R18, R22, R26, R30, R38, R42, R46: 10K; R_0603_1608Metric; Part # Generic 10K 1% 0402 Resistor
R13, R19, R23, R27, R35, R39, R43, R47: 100R; R_0603_1608Metric; Part # Generic 100R 1% 0402 Resistor
R14, R20, R24, R28, R36, R40, R44, R48: 1R; R_0603_1608Metric; Part # Generic 1R 2W 1% 2512 Resistor
R17, R21, R25, R29, R37, R41, R45, R49: 1K; R_0603_1608Metric; Part # Generic 1K 1% 0402 Resistor
U3, U6, U7, U8, U9, U10, U11, U12: SOT-23-5; Part # MCP6001

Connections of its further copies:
+3.3V: C12.1, C13.1, C14.1, C16.1, C17.1, C19.1, C20.1, C21.1, U3.5 (V+), U6.5 (V+), U7.5 (V+), U8.5 (V+), U9.5 (V+), U10.5 (V+), U11.5 (V+), U12.5 (V+); also elsewhere on the board
+24V: D8.1 (K), D12.1 (K), D14.1 (K), D16.1 (K), D18.1 (K), D20.1 (K), D22.1 (K), D24.1 (K), J6.1, J7.1, J8.1, J10.1, J11.1, J12.1, J13.1, J39.1; also elsewhere on the board
/SOLENOID1_EN: R11.2, R13.1; also elsewhere on the board
/SOLENOID1_FB: U3.1, U3.4 (-); also elsewhere on the board
/SOLENOID2_EN: R18.2, R19.1; also elsewhere on the board
/SOLENOID2_FB: U6.1, U6.4 (-); also elsewhere on the board
/SOLENOID3_EN: R22.2, R23.1; also elsewhere on the board
/SOLENOID3_FB: U7.1, U7.4 (-); also elsewhere on the board
/SOLENOID4_EN: R26.2, R27.1; also elsewhere on the board
/SOLENOID4_FB: U8.1, U8.4 (-); also elsewhere on the board
/SOLENOID5_EN: R30.2, R35.1; also elsewhere on the board
/SOLENOID5_FB: U9.1, U9.4 (-); also elsewhere on the board
/SOLENOID6_EN: R38.2, R39.1; also elsewhere on the board
/SOLENOID6_FB: U10.1, U10.4 (-); also elsewhere on the board
/SOLENOID7_EN: R42.2, R43.1; also elsewhere on the board
/SOLENOID7_FB: U11.1, U11.4 (-); also elsewhere on the board
/SOLENOID8_EN: R46.2, R47.1; also elsewhere on the board
/SOLENOID8_FB: U12.1, U12.4 (-); also elsewhere on the board
GND: C12.2, C13.2, C14.2, C16.2, C17.2, C19.2, C20.2, C21.2, D9.2 (A), D13.2 (A), D15.2 (A), D17.2 (A), D19.2 (A), D21.2 (A), D23.2 (A), D25.2 (A), J6.3, J7.3, J8.3, J10.3, J11.3, J12.3, J13.3, J39.3, R11.1, R14.1, R18.1, R20.1, R22.1, R24.1, R26.1, R28.1, R30.1, R36.1, R38.1, R40.1, R42.1, R44.1, R46.1, R48.1, U3.2 (V-), U6.2 (V-), U7.2 (V-), U8.2 (V-), U9.2 (V-), U10.2 (V-), U11.2 (V-), U12.2 (V-); also elsewhere on the board
unnamed: D8.2 (A), J6.2, Q2.3 (D)
unnamed: D9.1 (K), R17.2, U3.3 (+)
unnamed: D12.2 (A), J7.2, Q3.3 (D)
unnamed: D13.1 (K), R21.2, U6.3 (+)
unnamed: D14.2 (A), J8.2, Q4.3 (D)
unnamed: D15.1 (K), R25.2, U7.3 (+)
unnamed: D16.2 (A), J10.2, Q5.3 (D)
unnamed: D17.1 (K), R29.2, U8.3 (+)
unnamed: D18.2 (A), J11.2, Q6.3 (D)
unnamed: D19.1 (K), R37.2, U9.3 (+)
unnamed: D20.2 (A), J12.2, Q7.3 (D)
unnamed: D21.1 (K), R41.2, U10.3 (+)
unnamed: D22.2 (A), J13.2, Q9.3 (D)
unnamed: D23.1 (K), R45.2, U11.3 (+)
unnamed: D24.2 (A), J39.2, Q10.3 (D)
unnamed: D25.1 (K), R49.2, U12.3 (+)
unnamed: Q2.1 (G), R13.2
unnamed: Q2.2 (S), R14.2, R17.1
unnamed: Q3.1 (G), R19.2
unnamed: Q3.2 (S), R20.2, R21.1
unnamed: Q4.1 (G), R23.2
unnamed: Q4.2 (S), R24.2, R25.1
unnamed: Q5.1 (G), R27.2
unnamed: Q5.2 (S), R28.2, R29.1
unnamed: Q6.1 (G), R35.2
unnamed: Q6.2 (S), R36.2, R37.1
unnamed: Q7.1 (G), R39.2
unnamed: Q7.2 (S), R40.2, R41.1
unnamed: Q9.1 (G), R43.2
unnamed: Q9.2 (S), R44.2, R45.1
unnamed: Q10.1 (G), R47.2
unnamed: Q10.2 (S), R48.2, R49.1

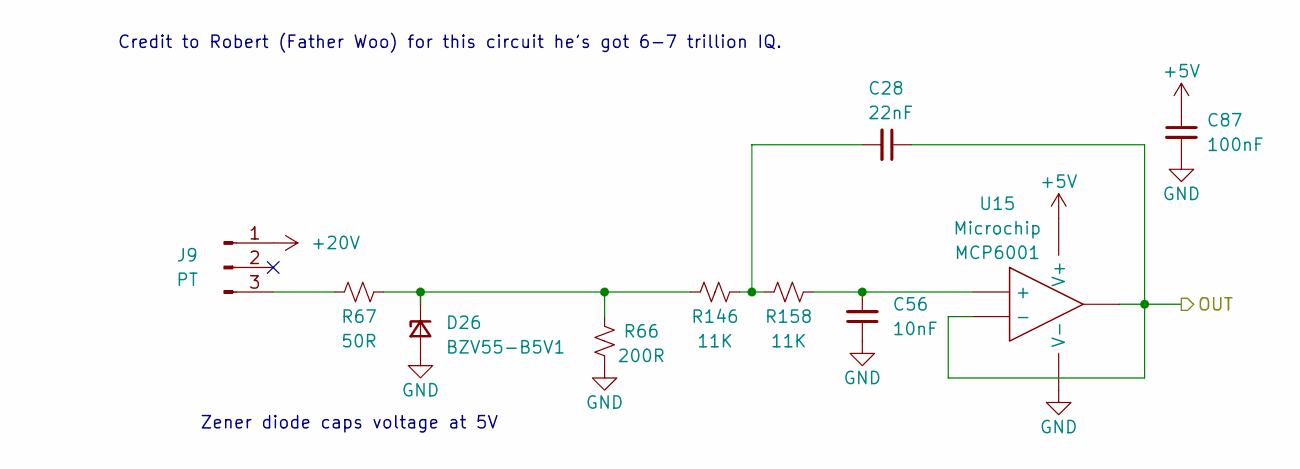
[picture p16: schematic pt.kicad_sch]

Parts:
C28: 22nF; C_0603_1608Metric; Part # Generic 100nF 6.3V X7R 0402 MLCC
C56: 10nF; C_0603_1608Metric; Part # Generic 100nF 6.3V X7R 0402 MLCC
C87: 100nF; C_0603_1608Metric; Part # Generic 100nF 6.3V X7R 0402 MLCC
D26: BZV55-B5V1; D_MiniMELF; Part # BZV55-B5V1
J9: PT; GX-12 3 pin
R66: 200R; R_0603_1608Metric; Part # Generic 1K 1% 0402 Resistor
R67: 50R; R_0603_1608Metric
R146, R158: 11K; R_0603_1608Metric; Part # Generic 1K 1% 0402 Resistor
U15: SOT-23-5; Part # MCP6001

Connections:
+5V: C87.1, U15.5 (V+); also elsewhere on the board
+20V: J9.1; also elsewhere on the board
/PT0_read: C28.1, U15.1, U15.4 (-)
GND: C56.1, C87.2, D26.2 (A), R66.1, U15.2 (V-); also elsewhere on the board
unnamed: C28.2, R146.1, R158.2
unnamed: D26.1 (K), R66.2, R67.1, R146.2
unnamed: J9.3, R67.2
unnamed: C56.2, R158.1, U15.3 (+)

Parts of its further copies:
C29, C30, C31, C34, C35, C36, C37, C38, C39, C40, C41: 22nF; C_0603_1608Metric; Part # Generic 100nF 6.3V X7R 0402 MLCC
C88, C89, C90, C91, C92, C93, C94, C95, C96, C97, C98: 100nF; C_0603_1608Metric; Part # Generic 100nF 6.3V X7R 0402 MLCC
C99, C100, C110, C111, C112, C113, C114, C115, C116, C117, C118: 10nF; C_0603_1608Metric; Part # Generic 100nF 6.3V X7R 0402 MLCC
D27, D28, D29, D30, D31, D32, D33, D34, D35, D36, D37: BZV55-B5V1; D_MiniMELF; Part # BZV55-B5V1
J19, J20, J21, J22, J23, J24, J25, J26, J27, J28, J29: PT; GX-12 3 pin
R68, R70, R72, R74, R76, R78, R80, R84, R86, R88, R90: 50R; R_0603_1608Metric
R69, R71, R73, R75, R77, R79, R81, R85, R87, R89, R91: 200R; R_0603_1608Metric; Part # Generic 1K 1% 0402 Resistor
R147, R148, R149, R150, R151, R152, R153, R154, R155, R156, R157, R159, R160, R161, R162, R163, R164, R165, R166, R167, R168, R169: 11K; R_0603_1608Metric; Part # Generic 1K 1% 0402 Resistor
U16, U17, U18, U20, U21, U22, U23, U24, U25, U28, U29: SOT-23-5; Part # MCP6001

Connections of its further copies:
+5V: C88.1, C89.1, C90.1, C91.1, C92.1, C93.1, C94.1, C95.1, C96.1, C97.1, C98.1, U16.5 (V+), U17.5 (V+), U18.5 (V+), U20.5 (V+), U21.5 (V+), U22.5 (V+), U23.5 (V+), U24.5 (V+), U25.5 (V+), U28.5 (V+), U29.5 (V+); also elsewhere on the board
+20V: J19.1, J20.1, J21.1, J22.1, J23.1, J24.1, J25.1, J26.1, J27.1, J28.1, J29.1; also elsewhere on the board
/PT1_read: C29.1, U16.1, U16.4 (-)
/PT2_read: C30.1, U17.1, U17.4 (-)
/PT3_read: C31.1, U18.1, U18.4 (-)
/PT4_read: C34.1, U20.1, U20.4 (-)
/PT5_read: C35.1, U21.1, U21.4 (-)
/PT6_read: C36.1, U22.1, U22.4 (-)
/PT7_read: C37.1, U23.1, U23.4 (-)
/PT8_read: C38.1, U24.1, U24.4 (-)
/PT9_read: C39.1, U25.1, U25.4 (-)
/PT10_read: C40.1, U28.1, U28.4 (-)
/PT11_read: C41.1, U29.1, U29.4 (-)
GND: C88.2, C89.2, C90.2, C91.2, C92.2, C93.2, C94.2, C95.2, C96.2, C97.2, C98.2, C99.1, C100.1, C110.1, C111.1, C112.1, C113.1, C114.1, C115.1, C116.1, C117.1, C118.1, D27.2 (A), D28.2 (A), D29.2 (A), D30.2 (A), D31.2 (A), D32.2 (A), D33.2 (A), D34.2 (A), D35.2 (A), D36.2 (A), D37.2 (A), R69.1, R71.1, R73.1, R75.1, R77.1, R79.1, R81.1, R85.1, R87.1, R89.1, R91.1, U16.2 (V-), U17.2 (V-), U18.2 (V-), U20.2 (V-), U21.2 (V-), U22.2 (V-), U23.2 (V-), U24.2 (V-), U25.2 (V-), U28.2 (V-), U29.2 (V-); also elsewhere on the board
unnamed: C29.2, R147.1, R159.2
unnamed: C30.2, R148.1, R160.2
unnamed: C31.2, R149.1, R161.2
unnamed: C34.2, R150.1, R162.2
unnamed: C35.2, R151.1, R163.2
unnamed: C36.2, R152.1, R164.2
unnamed: C37.2, R153.1, R165.2
unnamed: C38.2, R154.1, R166.2
unnamed: C39.2, R155.1, R167.2
unnamed: C40.2, R156.1, R168.2
unnamed: C41.2, R157.1, R169.2
unnamed: D27.1 (K), R68.1, R69.2, R147.2
unnamed: D28.1 (K), R70.1, R71.2, R148.2
unnamed: D29.1 (K), R72.1, R73.2, R149.2
unnamed: D30.1 (K), R74.1, R75.2, R150.2
unnamed: D31.1 (K), R76.1, R77.2, R151.2
unnamed: D32.1 (K), R78.1, R79.2, R152.2
unnamed: D33.1 (K), R80.1, R81.2, R153.2
unnamed: D34.1 (K), R84.1, R85.2, R154.2
unnamed: D35.1 (K), R86.1, R87.2, R155.2
unnamed: D36.1 (K), R88.1, R89.2, R156.2
unnamed: D37.1 (K), R90.1, R91.2, R157.2
unnamed: J19.3, R68.2
unnamed: J20.3, R70.2
unnamed: J21.3, R72.2
unnamed: J22.3, R74.2
unnamed: J23.3, R76.2
unnamed: J24.3, R78.2
unnamed: J25.3, R80.2
unnamed: J26.3, R84.2
unnamed: J27.3, R86.2
unnamed: J28.3, R88.2
unnamed: J29.3, R90.2
unnamed: C99.2, R159.1, U16.3 (+)
unnamed: C100.2, R160.1, U17.3 (+)
unnamed: C110.2, R161.1, U18.3 (+)
unnamed: C111.2, R162.1, U20.3 (+)
unnamed: C112.2, R163.1, U21.3 (+)
unnamed: C113.2, R164.1, U22.3 (+)
unnamed: C114.2, R165.1, U23.3 (+)
unnamed: C115.2, R166.1, U24.3 (+)
unnamed: C116.2, R167.1, U25.3 (+)
unnamed: C117.2, R168.1, U28.3 (+)
unnamed: C118.2, R169.1, U29.3 (+)

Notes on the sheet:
Zener diode caps voltage at 5V
Credit to Robert (Father Woo) for this circuit he's got 6-7 trillion IQ.

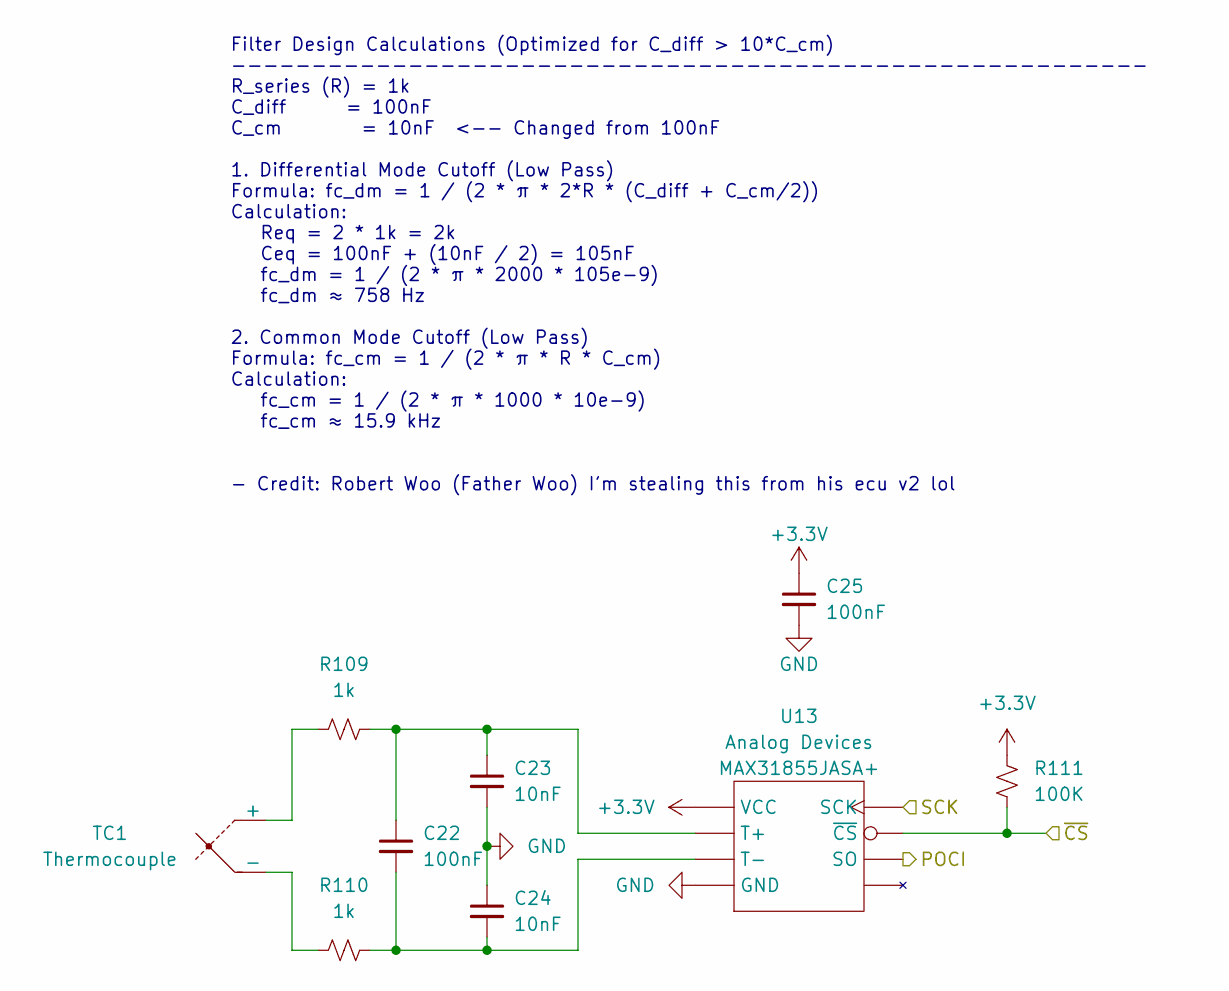
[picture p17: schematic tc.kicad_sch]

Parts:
C22, C25: 100nF; C_0603_1608Metric; Part # Generic CAP CER 0.1UF 6.3V X7R 0402
C23, C24: 10nF; C_0603_1608Metric; Part # Generic CAP CER 10NF 6.3V X7R 0402
R109, R110: 1k; R_0603_1608Metric; Part # Generic RES SMD 1K OHM 1% 1/16W 0402
R111: 100K; R_0603_1608Metric; Part # Generic RES SMD 100K OHM 1% 1/16W 0402
TC1: Thermocouple; AM-K-PCB; Part # AM-K-PCB
U13: SOIC-8_3.9x4.9mm_P1.27mm; Part # MAX31855JASA+

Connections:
+3.3V: C25.1, R111.1, U13.4 (VCC); also elsewhere on the board
/TC0_~CS: R111.2, U13.6 (~CS); also elsewhere on the board
/TC_POCI: U13.7 (SO); also elsewhere on the board
/TC_SCK: U13.5 (SCK); also elsewhere on the board
GND: C23.2, C24.1, C25.2, U13.1 (GND); also elsewhere on the board
unnamed: R109.1, TC1.1 (+)
unnamed: R110.1, TC1.2 (-)
unnamed: C22.1, C23.1, R109.2, U13.3 (T+)
unnamed: C22.2, C24.2, R110.2, U13.2 (T-)

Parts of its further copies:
C32, C64, C65, C68: 100nF; C_0603_1608Metric; Part # Generic CAP CER 0.1UF 6.3V X7R 0402
C33, C63, C66, C67: 10nF; C_0603_1608Metric; Part # Generic CAP CER 10NF 6.3V X7R 0402
R112, R113, R115, R116: 1k; R_0603_1608Metric; Part # Generic RES SMD 1K OHM 1% 1/16W 0402
R114, R117: 100K; R_0603_1608Metric; Part # Generic RES SMD 100K OHM 1% 1/16W 0402
TC2, TC3: Thermocouple; AM-K-PCB; Part # AM-K-PCB
U14, U19: SOIC-8_3.9x4.9mm_P1.27mm; Part # MAX31855JASA+

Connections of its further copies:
+3.3V: C64.1, C68.1, R114.1, R117.1, U14.4 (VCC), U19.4 (VCC); also elsewhere on the board
/TC1_~CS: R114.2, U14.6 (~CS); also elsewhere on the board
/TC2_~CS: R117.2, U19.6 (~CS); also elsewhere on the board
/TC_POCI: U14.7 (SO), U19.7 (SO); also elsewhere on the board
/TC_SCK: U14.5 (SCK), U19.5 (SCK); also elsewhere on the board
GND: C33.2, C63.1, C64.2, C66.2, C67.1, C68.2, U14.1 (GND), U19.1 (GND); also elsewhere on the board
unnamed: R112.1, TC2.1 (+)
unnamed: R113.1, TC2.2 (-)
unnamed: R115.1, TC3.1 (+)
unnamed: R116.1, TC3.2 (-)
unnamed: C32.1, C33.1, R112.2, U14.3 (T+)
unnamed: C32.2, C63.2, R113.2, U14.2 (T-)
unnamed: C65.1, C66.1, R115.2, U19.3 (T+)
unnamed: C65.2, C67.2, R116.2, U19.2 (T-)

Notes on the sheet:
Filter Design Calculations (Optimized for C_diff > 10*C_cm) --------------------------------------------------------- R_series (R) = 1k C_diff = 100nF C_cm = 10nF <-- Changed from 100nF 1. Differential Mode Cutoff (Low Pass) Formula: fc_dm = 1 / (2 * π * 2*R * (C_diff + C_cm/2)) Calculation: Req = 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

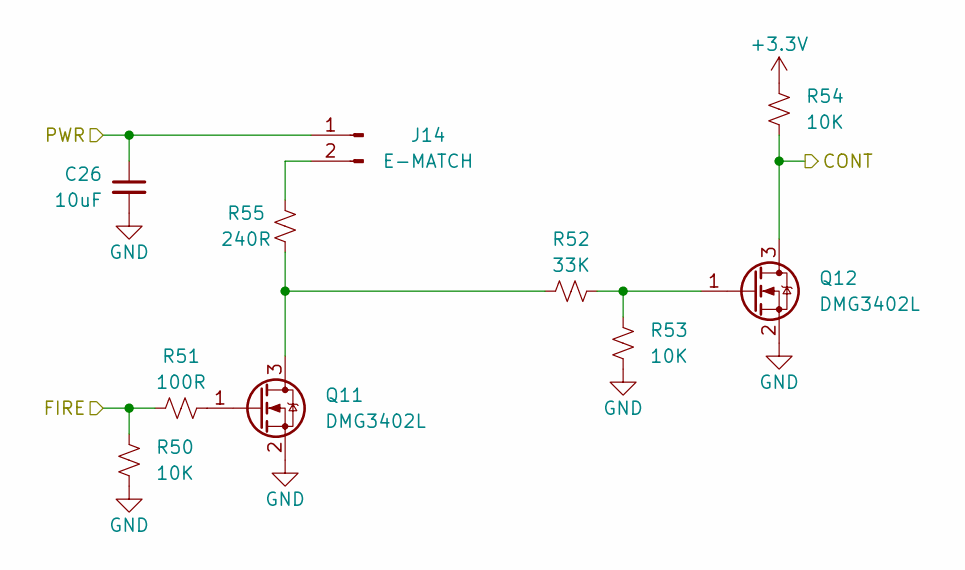
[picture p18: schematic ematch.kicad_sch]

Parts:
C26: 10uF; C_0603_1608Metric; Part # Generic 10uF 35V X5R 1206 MLCC
J14: E-MATCH; TerminalBlock_MetzConnect_Type055_RT01502HDWU_1x02_P5.00mm_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
Q11, Q12: DMG3402L; SOT-23-3; Part # DMG3402L
R50, R53, R54: 10K; R_0603_1608Metric; Part # Generic 10K 1% 0402 Resistor
R51: 100R; R_0603_1608Metric; Part # Generic 100R 1% 0402 Resistor
R52: 33K; R_0603_1608Metric; Part # Generic 33K 1% 0402 Resistor
R55: 240R; R_0603_1608Metric; Part # Generic 33K 1% 0402 Resistor

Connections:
+3.3V: R54.2; also elsewhere on the board
/E-Match0/PWR: C26.1, J14.1; also elsewhere on the board
/EMATCH0_CONT: Q12.3 (D), R54.1; also elsewhere on the board
/EMATCH0_FIRE: R50.2, R51.1; also elsewhere on the board
GND: C26.2, Q11.2 (S), Q12.2 (S), R50.1, R53.1; also elsewhere on the board
unnamed: J14.2, R55.2
unnamed: Q11.3 (D), R52.1, R55.1
unnamed: Q11.1 (G), R51.2
unnamed: Q12.1 (G), R52.2, R53.2

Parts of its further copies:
C27: 10uF; C_0603_1608Metric; Part # Generic 10uF 35V X5R 1206 MLCC
J15: E-MATCH; TerminalBlock_MetzConnect_Type055_RT01502HDWU_1x02_P5.00mm_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
Q13, Q14: DMG3402L; SOT-23-3; Part # DMG3402L
R56, R60, R61: 10K; R_0603_1608Metric; Part # Generic 10K 1% 0402 Resistor
R57: 100R; R_0603_1608Metric; Part # Generic 100R 1% 0402 Resistor
R58: 240R; R_0603_1608Metric; Part # Generic 33K 1% 0402 Resistor
R59: 33K; R_0603_1608Metric; Part # Generic 33K 1% 0402 Resistor

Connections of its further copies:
+3.3V: R61.2; also elsewhere on the board
/E-Match0/PWR: C27.1, J15.1; also elsewhere on the board
/EMATCH1_CONT: Q14.3 (D), R61.1; also elsewhere on the board
/EMATCH1_FIRE: R56.2, R57.1; also elsewhere on the board
GND: C27.2, Q13.2 (S), Q14.2 (S), R56.1, R60.1; also elsewhere on the board
unnamed: J15.2, R58.2
unnamed: Q13.3 (D), R58.1, R59.1
unnamed: Q13.1 (G), R57.2
unnamed: Q14.1 (G), R59.2, R60.2

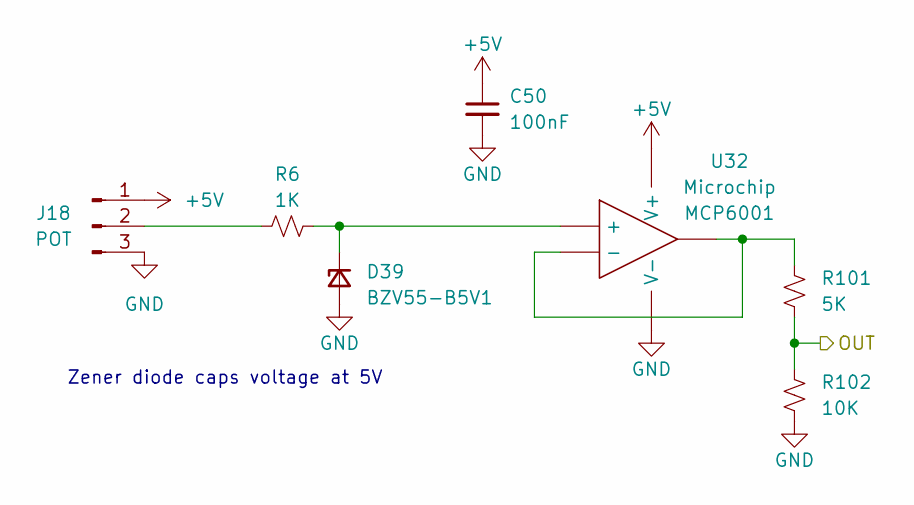
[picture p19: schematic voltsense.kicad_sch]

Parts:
C50: 100nF; C_0603_1608Metric; Part # Generic 100nF 6.3V X7R 0402 MLCC
D39: BZV55-B5V1; D_MiniMELF; Part # BZV55-B5V1
J18: POT; GX-12 3 pin
R6: 1K; R_0603_1608Metric; Part # Generic 1K 1% 0402 Resistor
R101: 5K; R_0603_1608Metric; Part # Generic 5K 1% 0402 Resistor
R102: 10K; R_0603_1608Metric; Part # Generic 10K 1% 0402 Resistor
U32: SOT-23-5; Part # MCP6001

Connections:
+5V: C50.1, J18.1, U32.5 (V+); also elsewhere on the board
/V_SENSE4: R101.1, R102.2; also elsewhere on the board
GND: C50.2, D39.2 (A), J18.3, R102.1, U32.2 (V-); also elsewhere on the board
unnamed: D39.1 (K), R6.2, U32.3 (+)
unnamed: J18.2, R6.1
unnamed: R101.2, U32.1, U32.4 (-)

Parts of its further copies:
C51, C58, C59, C60: 100nF; C_0603_1608Metric; Part # Generic 100nF 6.3V X7R 0402 MLCC
D40, D41, D46, D47: BZV55-B5V1; D_MiniMELF; Part # BZV55-B5V1
J32, J36, J37, J38: POT; GX-12 3 pin
R103, R107, R120, R123: 1K; R_0603_1608Metric; Part # Generic 1K 1% 0402 Resistor
R105, R118, R121, R124: 5K; R_0603_1608Metric; Part # Generic 5K 1% 0402 Resistor
R106, R119, R122, R125: 10K; R_0603_1608Metric; Part # Generic 10K 1% 0402 Resistor
U34, U35, U37, U39: SOT-23-5; Part # MCP6001

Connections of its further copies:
+5V: C51.1, C58.1, C59.1, C60.1, J32.1, J36.1, J37.1, J38.1, U34.5 (V+), U35.5 (V+), U37.5 (V+), U39.5 (V+); also elsewhere on the board
/V_SENSE0: R118.1, R119.2; also elsewhere on the board
/V_SENSE1: R105.1, R106.2; also elsewhere on the board
/V_SENSE2: R121.1, R122.2; also elsewhere on the board
/V_SENSE3: R124.1, R125.2; also elsewhere on the board
GND: C51.2, C58.2, C59.2, C60.2, D40.2 (A), D41.2 (A), D46.2 (A), D47.2 (A), J32.3, J36.3, J37.3, J38.3, R106.1, R119.1, R122.1, R125.1, U34.2 (V-), U35.2 (V-), U37.2 (V-), U39.2 (V-); also elsewhere on the board
unnamed: D40.1 (K), R103.2, U34.3 (+)
unnamed: D41.1 (K), R107.2, U35.3 (+)
unnamed: D46.1 (K), R120.2, U37.3 (+)
unnamed: D47.1 (K), R123.2, U39.3 (+)
unnamed: J32.2, R103.1
unnamed: J36.2, R107.1
unnamed: J37.2, R120.1
unnamed: J38.2, R123.1
unnamed: R105.2, U34.1, U34.4 (-)
unnamed: R118.2, U35.1, U35.4 (-)
unnamed: R121.2, U37.1, U37.4 (-)
unnamed: R124.2, U39.1, U39.4 (-)

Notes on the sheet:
Zener diode caps voltage at 5V

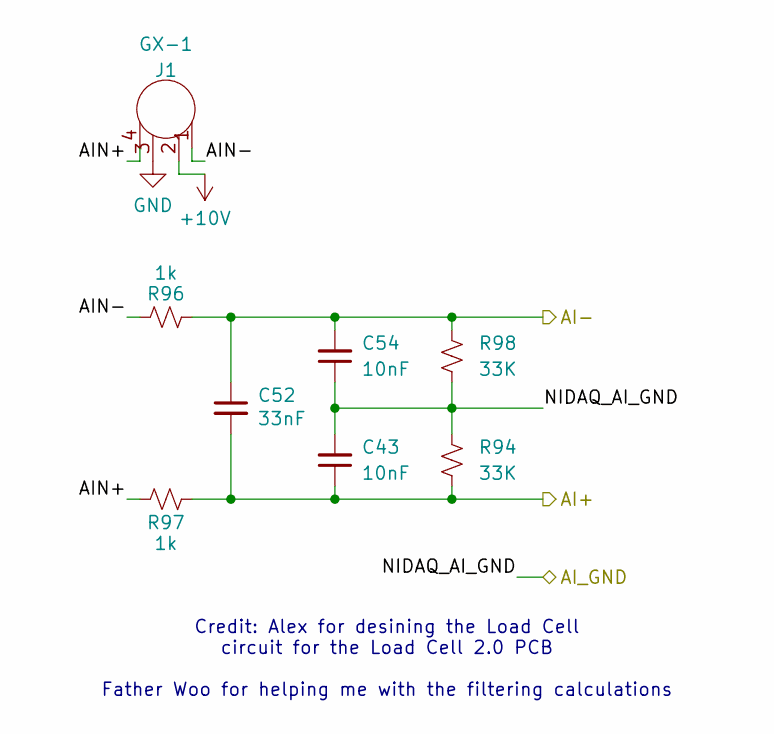
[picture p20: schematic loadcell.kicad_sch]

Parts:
C43, C54: 10nF; C_0603_1608Metric
C52: 33nF; C_0603_1608Metric
GX-1: J1; GX16-4
R94, R98: 33K; R_0603_1608Metric; Part # Generic 33K 1% 0402 Resistor
R96, R97: 1k; R_0603_1608Metric

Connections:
+10V: GX-1.2; also elsewhere on the board
/LC0_AI+: C43.1, C52.2, R94.1, R97.2
/LC0_AI-: C52.1, C54.2, R96.1, R98.2
/LoadCell0/AIN+: GX-1.4, R97.1
/LoadCell0/AIN-: GX-1.1, R96.2
GND: C43.2, C54.1, GX-1.3, R94.2, R98.1; also elsewhere on the board

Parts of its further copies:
C42: 33nF; C_0603_1608Metric
C49, C62: 10nF; C_0603_1608Metric
GX-2: J1; GX16-4
R92, R93: 1k; R_0603_1608Metric
R95, R99: 33K; R_0603_1608Metric; Part # Generic 33K 1% 0402 Resistor

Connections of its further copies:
+10V: GX-2.2; also elsewhere on the board
/LC1_AI+: C42.2, C49.1, R93.2, R95.1
/LC1_AI-: C42.1, C62.2, R92.1, R99.2
/LoadCell1/AIN+: GX-2.4, R93.1
/LoadCell1/AIN-: GX-2.1, R92.2
GND: C49.2, C62.1, GX-2.3, R95.2, R99.1; also elsewhere on the board

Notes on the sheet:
Credit: Alex for desining the Load Cell circuit for the Load Cell 2.0 PCB Father Woo for helping me with the filtering calculations

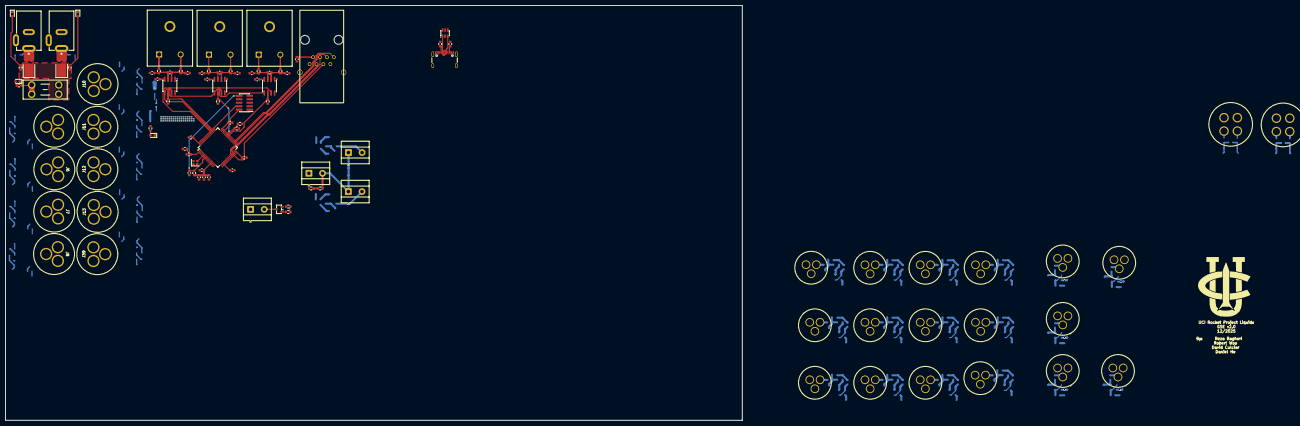
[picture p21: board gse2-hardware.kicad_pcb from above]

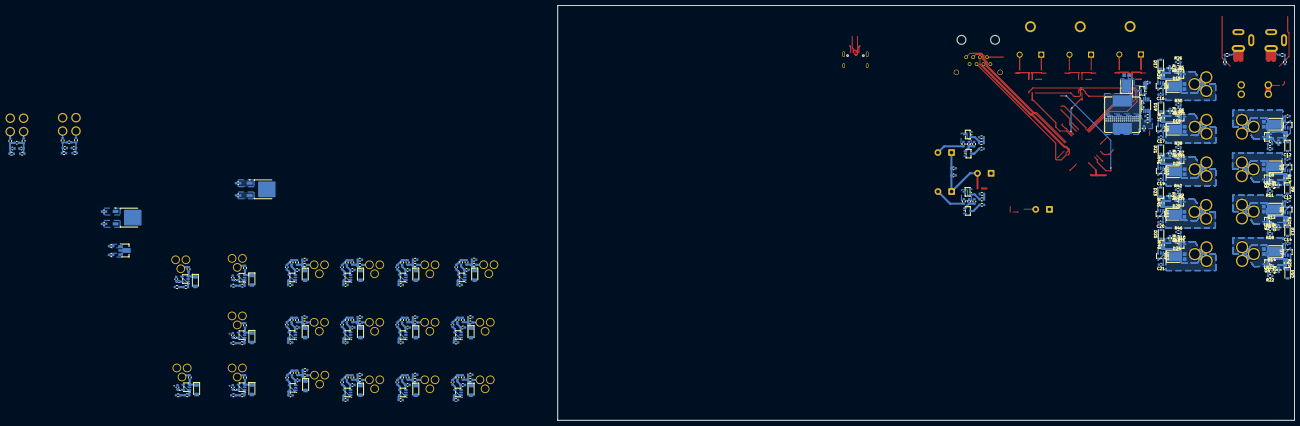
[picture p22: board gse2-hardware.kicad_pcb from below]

Board: 4 copper layers, 270.0 x 152.0 mm, 372 parts (272 on the bottom side), 211 nets.

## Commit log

2025-12-17 Updated to include most of the new schematic. only thing missing is NIDAQ interface and the correct connectors (GX12 and GX16) which I will get from the loadcell board. NIDAQ interface situation is a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
    [ematch.kicad_sch, gse2-hardware.kicad_pcb, gse2-hardware.kicad_sch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]
2025-12-18 Updated schematic. No filtering but besides that finished. Need to fix footprints and start layout.
    [420ext.kicad_sch, gse2-hardware.kicad_sch, loadcell.kicad_sch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]
2025-12-20 Added LC filter for power filtering
    [420ext.kicad_sch, ematch.kicad_sch, gse2-hardware.kicad_pcb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]
2025-12-21 Removed extra filtering circuit
    [gse2-hardware.kicad_sch, loadcell.kicad_sch]
2025-12-21 Fixed net names
    [gse2-hardware.kicad_sch]
2025-12-25 Updates after PDR
    [420ext.kicad_sch, gse2-hardware.kicad_sch, loadcell.kicad_sch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]
2025-12-26 Updated kicad lib commit, maybe correct now
    [solenoid.kicad_sch]
2025-12-26 Updated to add beginnings of layout. Most major subsystems internally layed out
    [420ext.kicad_sch, gse2-hardware.kicad_pcb, pt.kicad_sch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]
2025-12-28 Updated to add new filtering circuit
    [gse2-hardware.kicad_pcb, gse2-hardware.kicad_sch, loadcell.kicad_sch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]
2025-12-28 Subsystem level layout done (prelim)
    [ematch.kicad_sch, gse2-hardware.kicad_pcb, gse2-hardware.kicad_sch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]
2026-01-12 Good progress on full system layout.
    [gse2-hardware.kicad_pcb, gse2-hardware.kicad_sch, loadcell.kicad_sch]
2026-01-15 Layed out (no edge cuts)g
    [gse2-hardware.kicad_sch]
2026-01-16 Fixed updates form last night not pushing
    [gse2-hardware.kicad_sch]
2026-01-21 Fixed 4-20 ma to support 0-5v
    [pt.kicad_sch]
2026-01-21 All on back + new circuit
    [pt.kicad_sch]
2026-01-21 Fixed connectors
    [gse2-hardware.kicad_sch]
2026-01-22 Ready to order besides BOM. I might mess w/ silkscreen more. 3v3 reg changed
    [gse2-hardware.kicad_sch]
2026-03-24 GSE v2.1: Updates for DSUB connectors for schematic only done. Layout needs a ton of work
    [ematch.kicad_sch, gse2-hardware.kicad_sch, loadcell.kicad_sch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]
2026-03-24 GSE v2.1: placement 70% done, still need to do a lot of routing
    [loadcell.kicad_sch]
2026-03-26 GSE v2.1: routing for NI stuff done, need to do a lot of stm32 and power routing now
    [gse2-hardware.kicad_sch]
2026-03-29 GSE v2.1: Routing 90% done
    [gse2-hardware.kicad_sch]
2026-03-30 GSE v2.1: Routing and Silkscreen done, need to review and check LDO pinouts
2026-03-31 GSE v2.1 done, just waiting on prop rn to finalize their sensor list
    [ematch.kicad_sch, gse2-hardware.kicad_sch, loadcell.kicad_sch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]
2026-04-01 GSE v2.1: small changes made and typos
    [gse2-hardware.kicad_sch, loadcell.kicad_sch, pt.kicad_sch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]
2026-04-05 GSEv2.1: changed pinout for PT and Loadcell where pin11 on VGA is grounded
    [loadcell.kicad_sch, pt.kicad_sch]
2026-04-22 GSE v2.1: Done, ready for JLCPCB
    [ematch.kicad_sch, gse2-hardware.kicad_sch, loadcell.kicad_sch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]
